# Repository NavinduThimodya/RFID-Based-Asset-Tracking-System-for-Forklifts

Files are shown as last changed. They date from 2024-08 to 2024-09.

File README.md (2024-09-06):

### RFID-Based Asset Tracking Device for Forklifts

#### Overview:

This project aims to develop an RFID-based asset tracking device for forklifts, enhancing asset management efficiency in warehouse environments. The device utilizes RFID technology for asset identification and tracking, integrating with existing forklift systems to provide real-time visibility of asset movements. The system consists of an RFID reader mounted on the forklift, antennas for RFID signal transmission and reception, and a cloud-based platform for data storage and analysis.

#### Features:

*   **RFID Technology:** Utilizes HF RFID technology (13.56MHz) for asset tracking, ensuring reliable and accurate identification.
*   **Real-Time Tracking:** Provides real-time visibility of asset movements, enabling efficient inventory management and asset utilization.
*   **Cloud Connectivity:** Integrates with cloud-based platforms for data storage, analysis, and remote access.
*   **User Interface:** Includes LEDs and a buzzer for user feedback, indicating successful RFID reads and system status.
*   **Low Power Consumption:** Designed for low power consumption, ensuring long-term operation without frequent recharging or replacement of batteries.

#### Components:

*   **PN532 RFID Reader:** Interfaces with RFID tags to read and write data, enabling asset tracking functionality.
*   **ESP32 WROOM 32:** Provides WiFi connectivity for data transmission to cloud servers, enabling real-time tracking updates.
*   **LM2596S-3.3 Voltage Regulator:** Converts the 12V forklift battery voltage to 3.3V for powering the ESP32 and PN532.
*   **Antenna and Matching Circuit:** Enables efficient transmission and reception of RFID signals, ensuring reliable asset tracking.

#### Installation:

1.  **Mounting:** Attach the RFID reader and antennas to the forklift as per the installation instructions.
2.  **Power Supply:** Connect the device to the forklift battery using the provided power cable.
3.  **Network Connection:** Configure the device to connect to the WiFi network in the warehouse.
4.  **Software Setup:** Install the necessary software on the forklift's onboard computer to receive and process RFID data.

#### Usage:

1.  **Asset Tagging:** Attach RFID tags to assets to be tracked, ensuring they are within the reader's range.
2.  **Asset Tracking:** Drive the forklift as usual, and the RFID reader will automatically scan nearby assets and update their locations in real-time.
3.  **Data Analysis:** Use the cloud-based platform to analyze asset movements, optimize inventory placement, and improve overall warehouse efficiency.

#### Maintenance:

*   **Regular Inspections:** Periodically check the device for any physical damage or loose connections.
*   **Software Updates:** Keep the device's software up to date to ensure optimal performance and compatibility with the cloud platform.
*   **Battery Replacement:** Replace the forklift battery as needed to maintain continuous power supply to the device.

#### For More Details:

For a more detailed description of the project, including design specifications, circuit diagrams, and enclosure designs, please refer to the project's design document.

#### Achieving recognition as one of the top 3 projects in the module highlights my ability to deliver high-quality solutions that meet both technical and practical challenges. This accomplishment reflects my commitment to innovation, precision, and impactful engineering design.

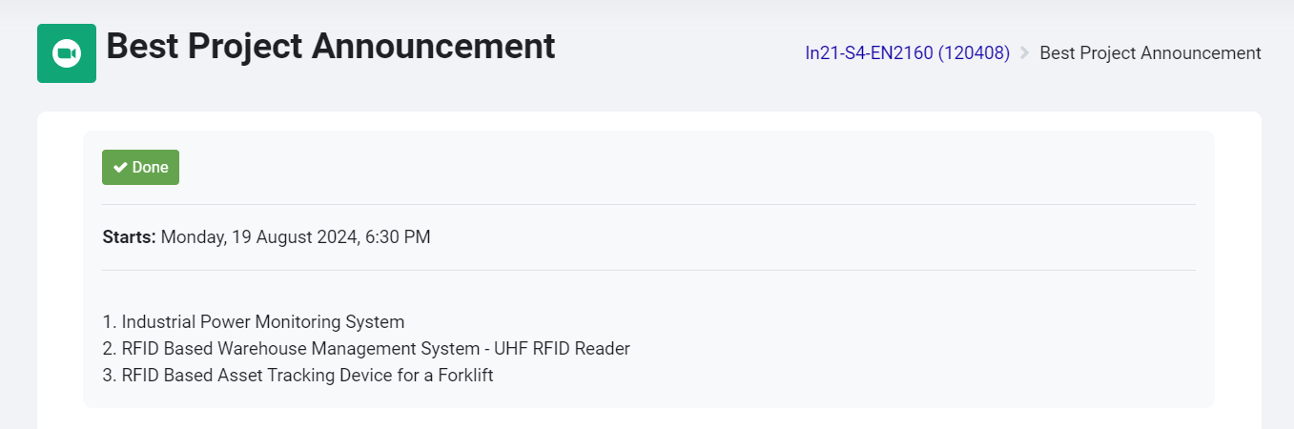
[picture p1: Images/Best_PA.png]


* * *

#### Enclosure Design:
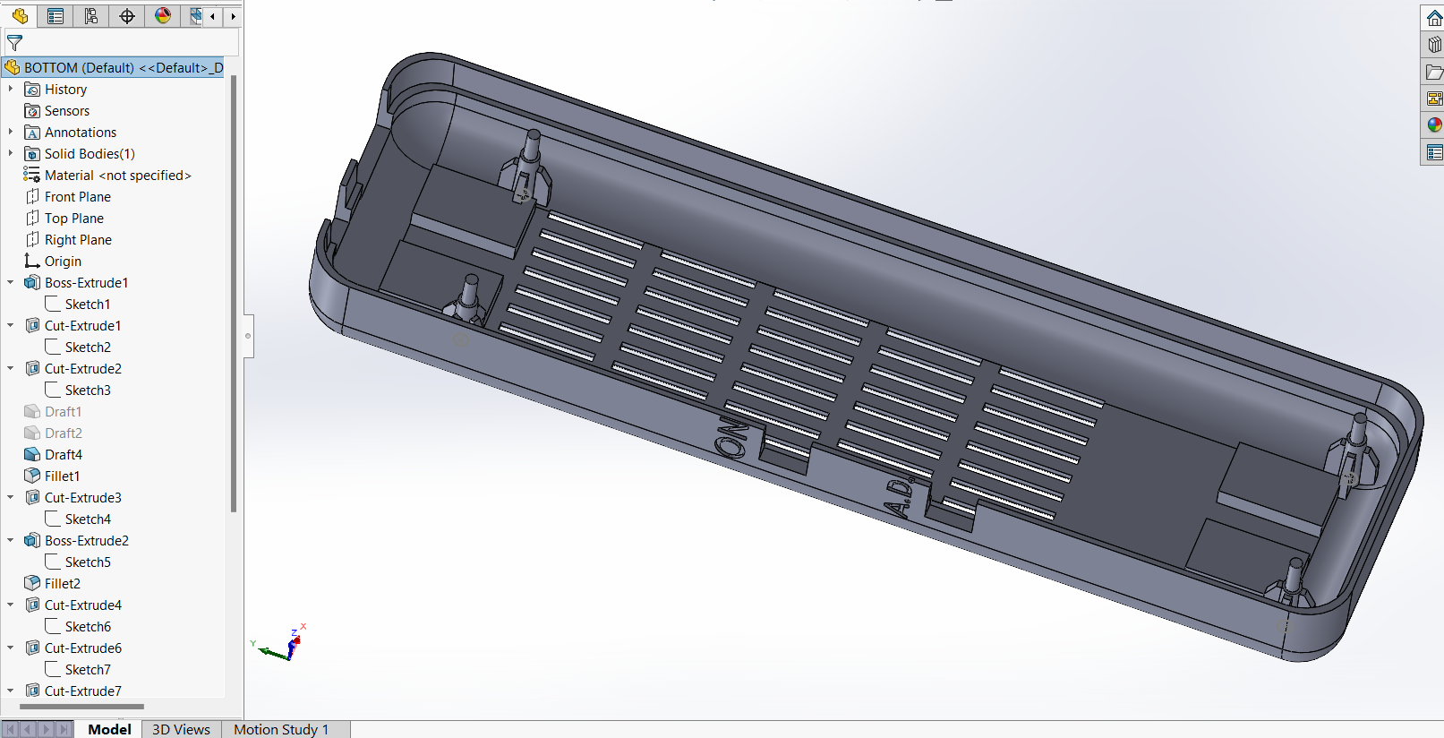
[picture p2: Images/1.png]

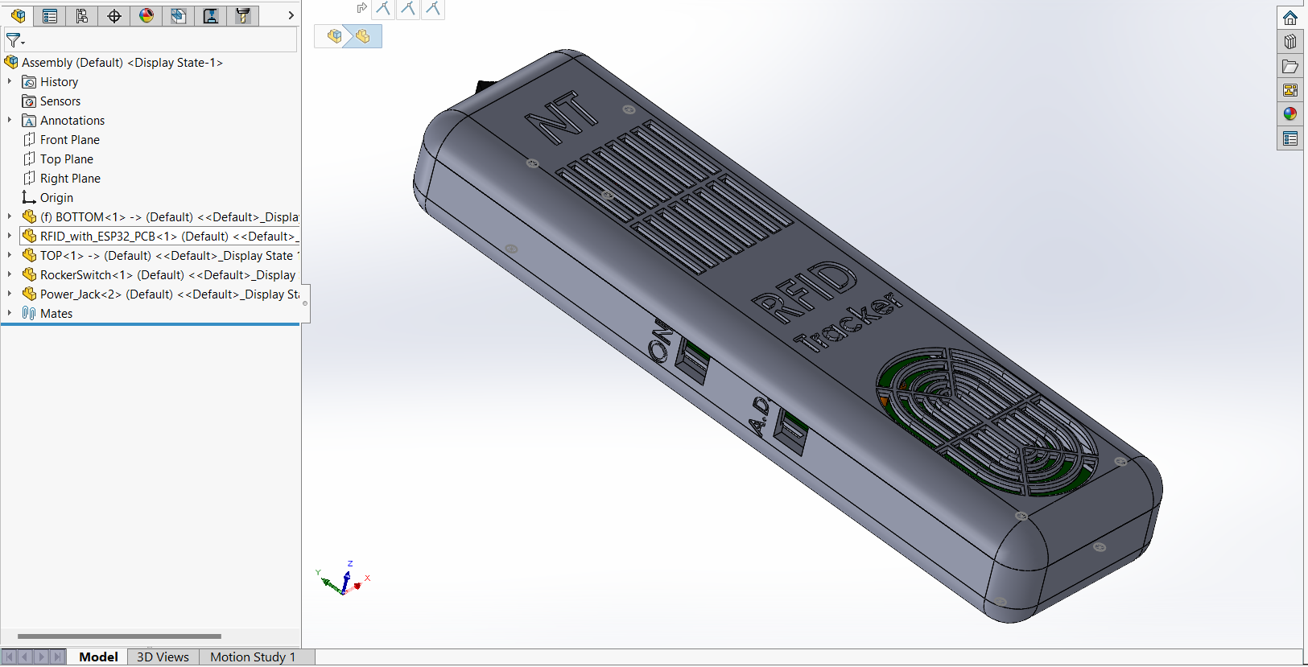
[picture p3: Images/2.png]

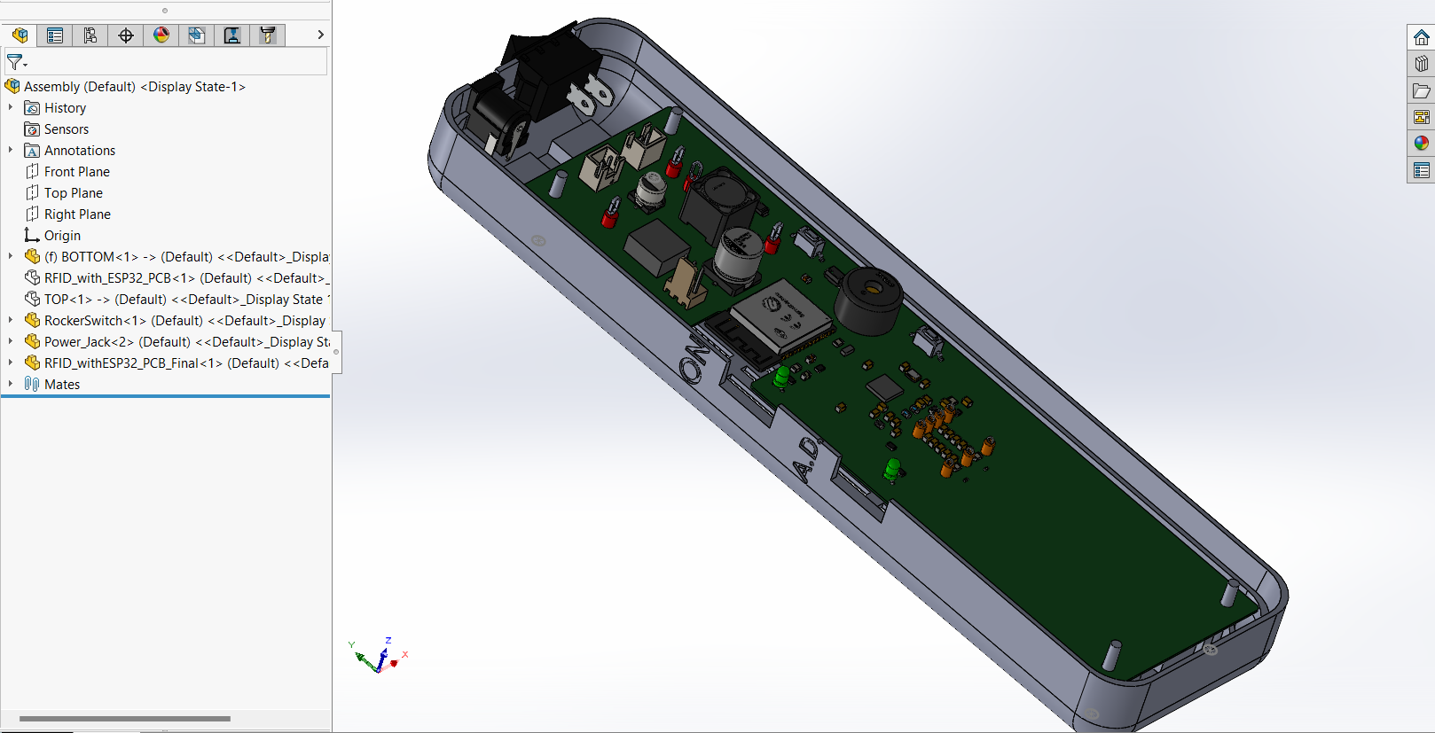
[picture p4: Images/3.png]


#### PCB Design:
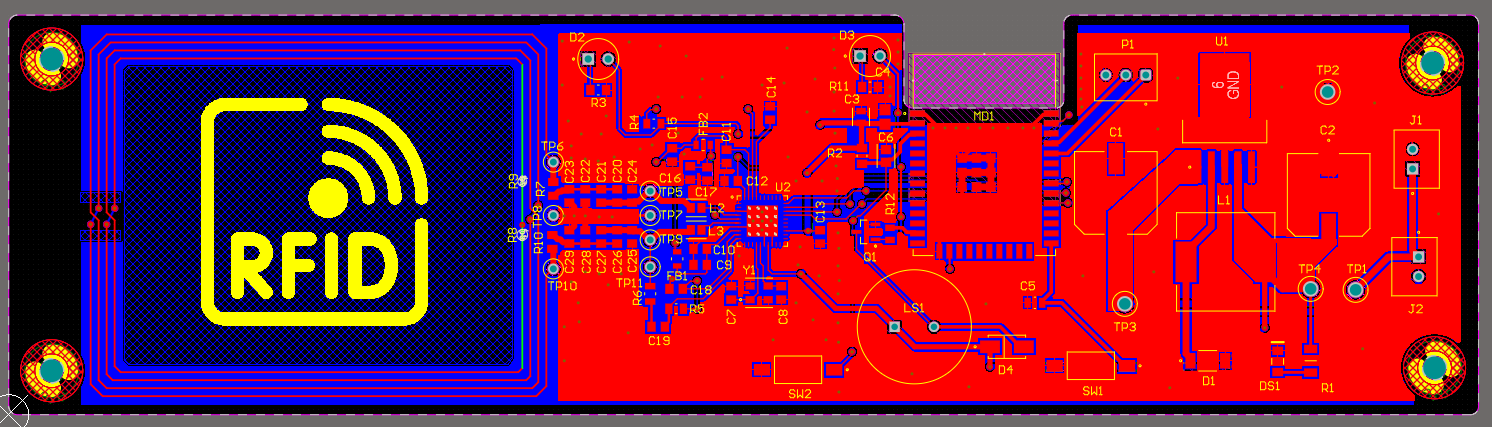
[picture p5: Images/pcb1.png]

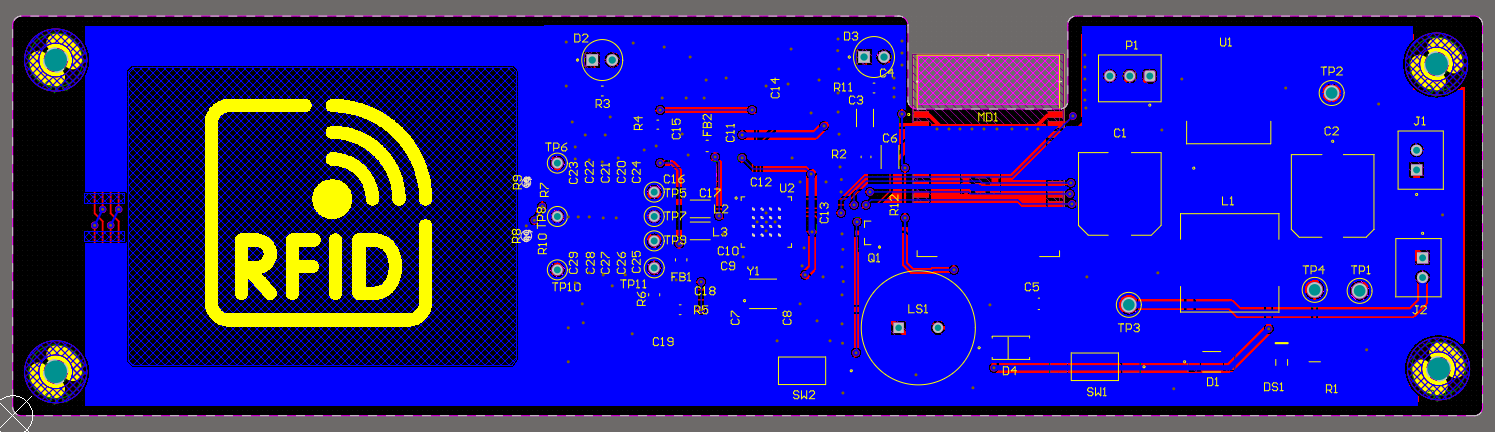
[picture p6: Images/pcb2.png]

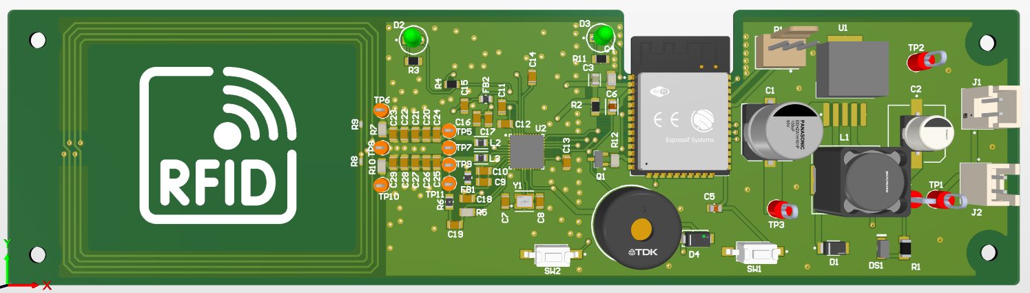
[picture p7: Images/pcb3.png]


#### Printed PCB:
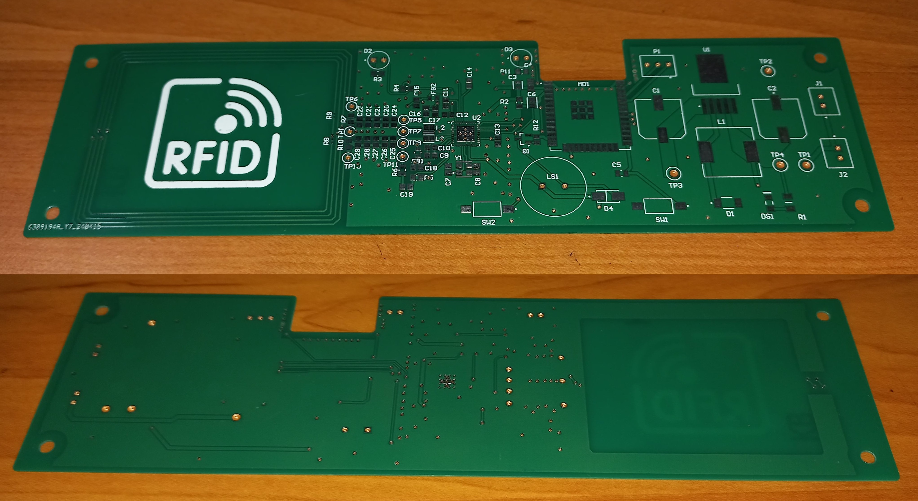
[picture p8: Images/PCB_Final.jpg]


#### Enclosure:
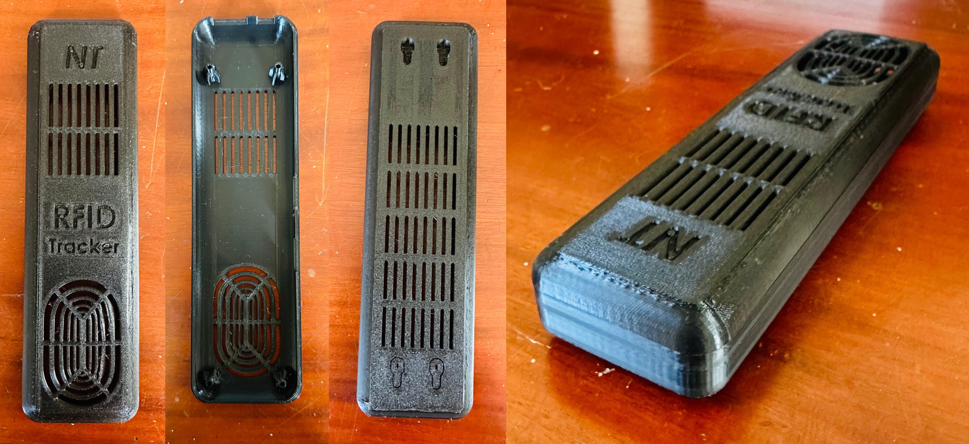
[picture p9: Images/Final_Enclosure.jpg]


#### Prototype:
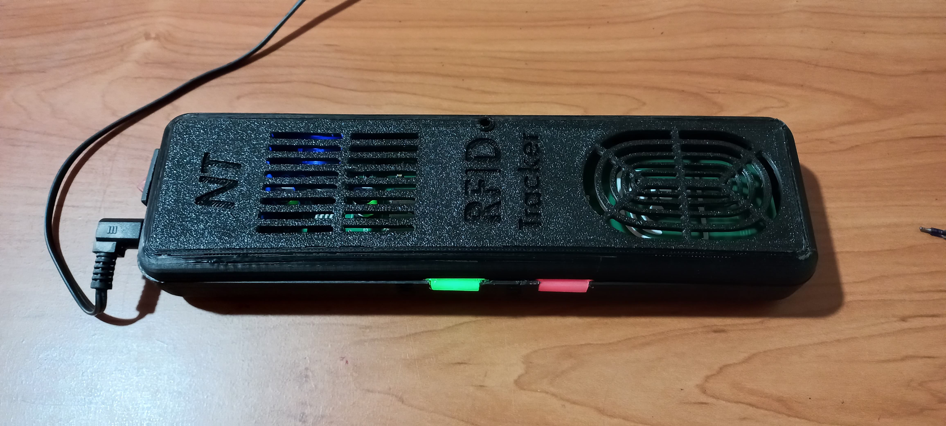
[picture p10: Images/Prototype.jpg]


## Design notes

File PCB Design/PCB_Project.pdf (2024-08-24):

Line # | Name | Description | Designator | Revision ID | Revision State | Revision Status | Quantity | Manufacturer 1 | Manufacturer Part Number 1 | Manufacturer Lifecycle 1 | Supplier 1 | Supplier Part Number 1 | Supplier Unit Price 1 | Supplier Subtotal 1
| 470uF | CAP ALUM POLY HYB 100UF 50V SMD | C1 | | Unknown server | | 1 | Panasonic | EEH-ZA1H101P | Volume Production
| 330uF | CAP ALUM 330UF 20% 35V SMD | C2 | | Unknown server | | 1 | Panasonic | EEE-FK1V331AP | Volume Production
| 10uF | CAP CER 10UF 10V X5R 0805 | C3 | | Unknown server | | 1
| 0.1uF | | C4 | | Unknown server | | 1
| 100nF | CAP CER 0.1UF 50V X7R 0805 | C5 | | Unknown server | | 1
| 100nF | General Purpose Ceramic Capacitor, 0805, 100nF, 10%, X7R, 15%, 100V | C6 | | Unknown server | | 1
| 33pF, 0.1uF, 10uF, 1000pF, NC, 22pF, 100pF, 220pF | Chip Capacitor, 0.1 uF, +/- 10%, 50 V, -55 to 125 degC, 0805 (2012 Metric), RoHS, Tape and Reel | C7, C8, C9, C10, C11, C12, C13, C14, C15, C16, C17, C18, C19, C20, C21, C22, C23, C24, C25, C26, C27, C28, C29 | | Unknown server | | 23
| CMS06(TE12L,Q,M) | DIODE SCHOTTKY 30V 2A MFLAT | D1 | | Unknown server | | 1 | Toshiba | CMS06(TE12L,Q,M) | Volume Production
| Power-LED, Detect-LED | TLLG4400 Led, Pcb, Green, 0.63MCD, 3MM, T-1, 7MA, 1.9V, 565NM, 25DEG, 20V, 20MW, -40 | D2, D3 | | Unknown server | | 2
| RS1M | DIODE GEN PURP 1KV 1A SMA | D4 | | Unknown server | | 1
| SML-LX1206IC-TR | LED Red, 65 mW, -40 to 85 degC, 2-Pin SMD, RoHS, Tape and Reel | DS1 | | Unknown server | | 1 | Lumex | SMLLX1206ICTR | Volume Production
| HZ0805B272R-10 | FERRITE BEAD 100 OHM 0805 1LN | FB1, FB2 | | Unknown server | | 2
| B2B-XH-A(LF)(SN), Switch | CONN HEADER VERT 2POS 2.5MM, To power Switch | J1, J2 | | Unknown server | | 2 JST | | B2B-XH-A(LF)(SN) | Volume Production
| SRR1210-101M | FIXED IND 100UH 2.5A 135MOHM SMD | L1 | | Unknown server | | 1 | Bourns | SRR1210-101M | Volume Production
| 560nH | Multilayer Type Inductor for General Circuits, 0805 (2012), 0.56μH, 10%, 0.63Ω, 150mA | L2, L3 | | Unknown server | | 2
| BUZZER | AUDIO PIEZO TRANSDUCER 30V TH | LS1 | | Unknown server | | 1
| ESP32-WROOM-32 | RX TXRX MOD WIFI SURFACE MOUNT | MD1 | | Unknown server | | 1 | Espressif Systems | ESP32-WROOM-32
| 61900311121 | | P1 | | Unknown server | | 1
| BC847C | NPN Silicon AF Transistor, 45 V VCEO, 100 mA IC, SOT23, Reel, Green | Q1 | | Unknown server | | 1
| 1K | Resistor | R1 | | Not managed | | 1
| 1K | Chip Resistor, 1 KOhm, +/- 1%, 125 mW, -55 to 155 degC, 0805 (2012 Metric), RoHS, Tape and Reel | R2 | | Unknown server | | 1
| 10R | Chip Resistor, 10 Ohm, +/- 1%, 0.125 W, -55 to 155 degC, 0805 (2012 Metric), RoHS, Tape and Reel | R3, R11 | | Unknown server | | 2
| 10K | Chip Resistor, 10 KOhm, +/- 1%, 0.125 W, -55 to 155 degC, 0805 (2012 Metric), RoHS, Tape and Reel | R4 | | Unknown server | | 1
| 1.0K | | R5 | | Unknown server | | 1
| 1.69K | RES Thick Film, 1.5kΩ, 1%, 0.125W, 100ppm/°C, 0805 | R6 | | Unknown server | | 1
| 1.5 | | R7, R10 | | Unknown server | | 2
| NC | | R8, R9 | | Unknown server | | 2
| 220R | | R12 | | Unknown server | | 1
| Boot Button, RESET Button | FSMSM Push Button Switch, 50 mA, -35 to 85 degC, 2-Pin SMD, RoHS, Bulk | SW1, SW2 | | Unknown server | | 2
| 12V_IN, GND, 12V, 3.3V | Test Point, Red, Through Hole, RoHS, Bulk | TP1, TP2, TP3, TP4 | | Unknown server | | 4
| TX1_POST, TX1_PRE, TGND, TX2_POST, TX2_PRE, RX | Test Point, Orange, 1-Pin THD, RoHS | TP5, TP6, TP7, TP8, TP9, TP10, TP11 | | Unknown server | | 7
| LM2596S-3.3 | SIMPLE SWITCHER® Power Converter 150 KHz 3A Step-Down Voltage Regulator, 5-pin TO-263 | U1 | | Unknown server | | 1 | TI National Semiconductor | LM2596S-3.3 | End of Life
| PN5321A3HN/C106;55 | NFC Controller, 13.56 MHz, -30 to 85 degC, 40-Pin HVQFN (SOT618-1), RoHS, Tray | U2 | | Unknown server | | 1
| ABM8-27.120MHZ-B4-T | Crystal 27.12MHz ±30ppm 18pF SMD-4 3.2mm x 2.5mm | Y1 | | Unknown server | | 1

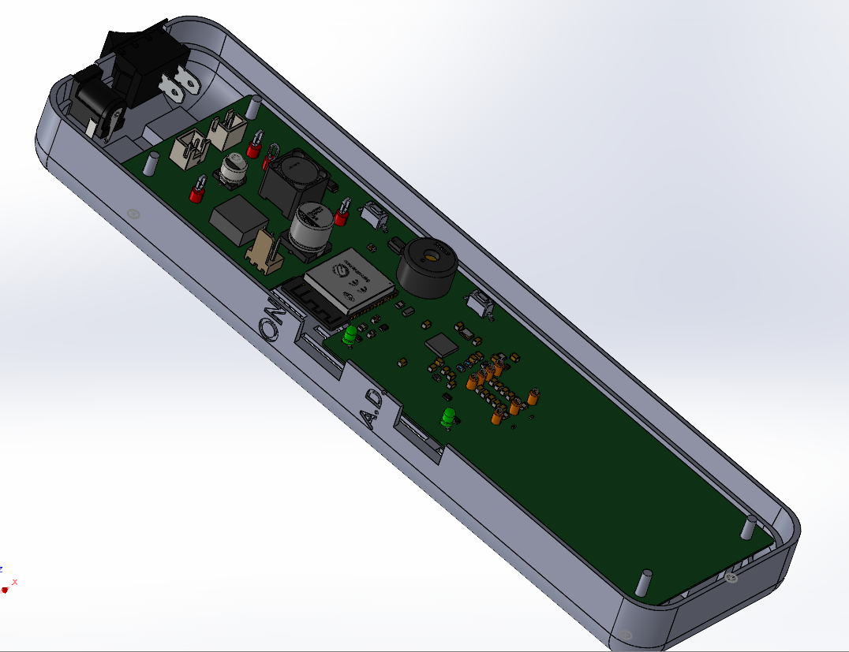
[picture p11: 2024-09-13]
Images/3 - Copy.png

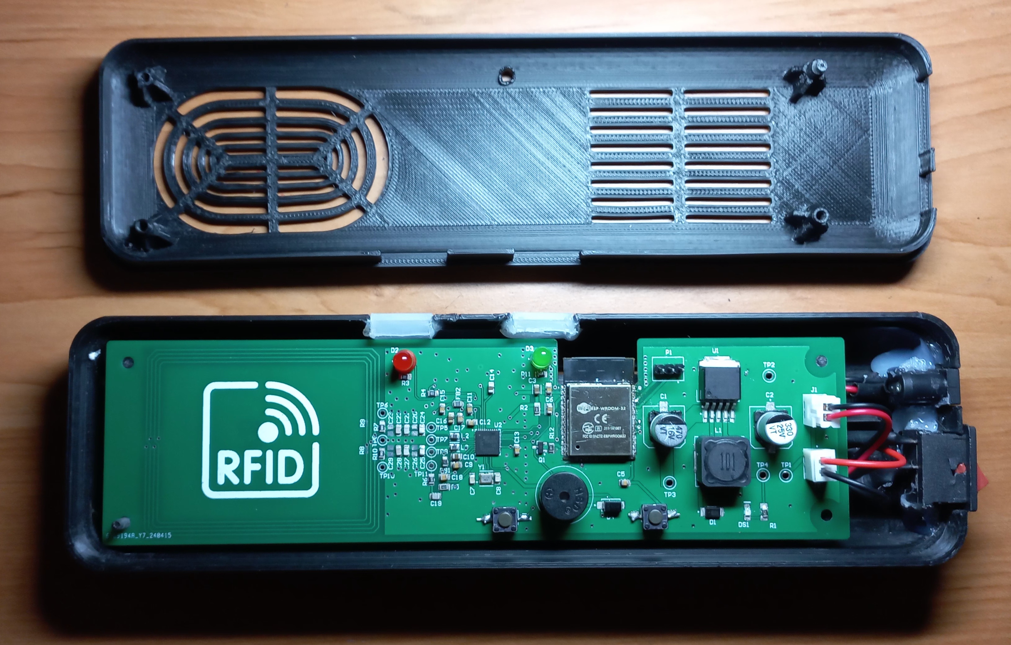
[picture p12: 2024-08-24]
Images/Integration.jpg

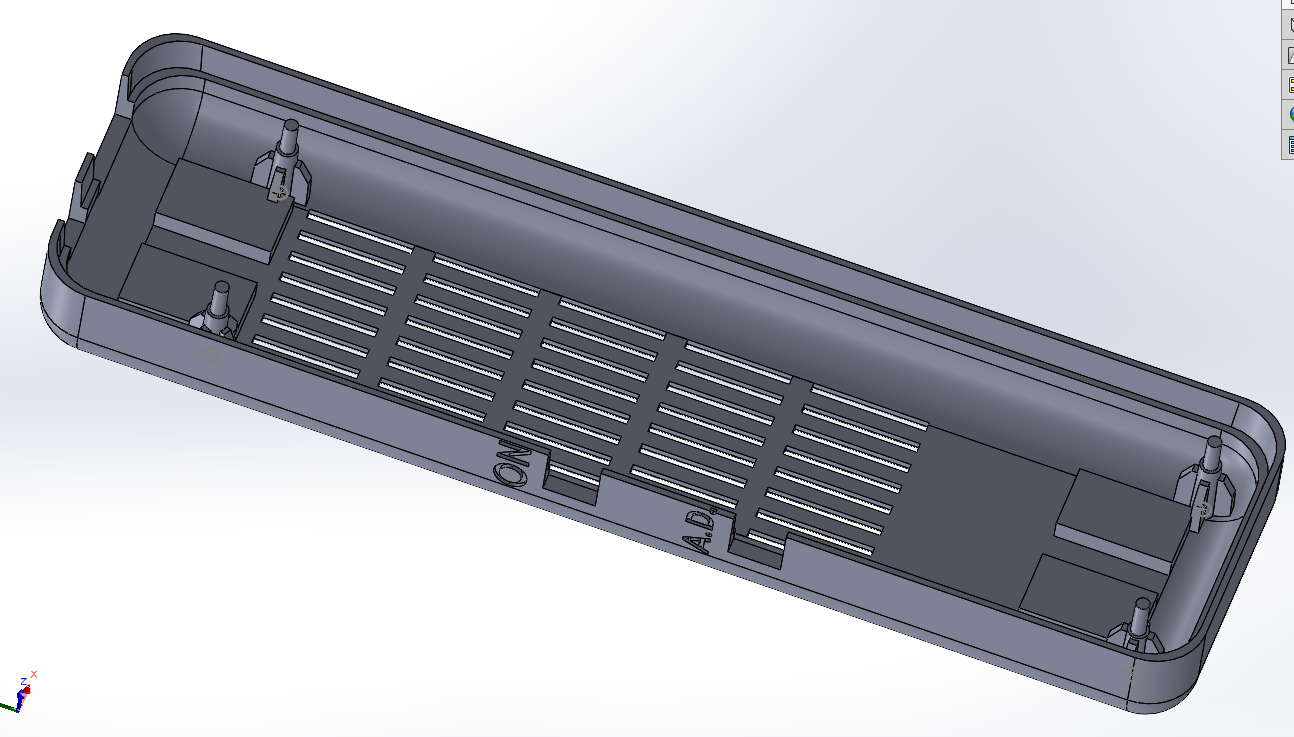
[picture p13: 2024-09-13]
Images/1 - Copy.png

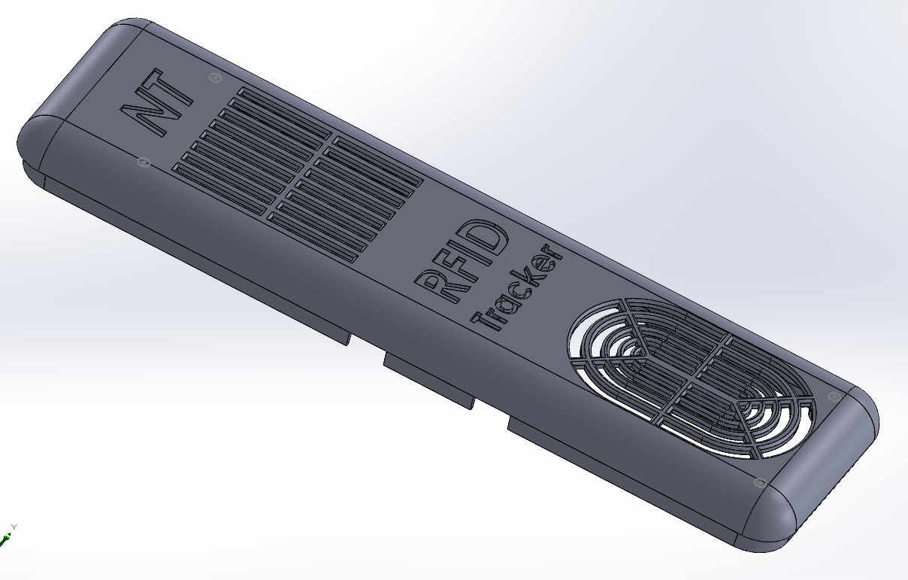
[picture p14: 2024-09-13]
Images/4 - Copy.png

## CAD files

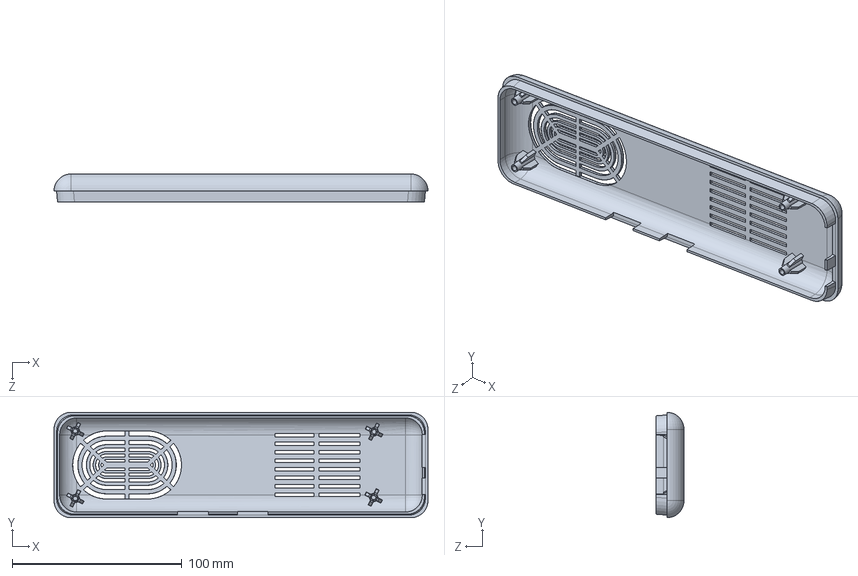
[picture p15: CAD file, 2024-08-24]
Enclosure Design/TOP.SLDPRT
220.0 x 62.0 x 16.5 mm

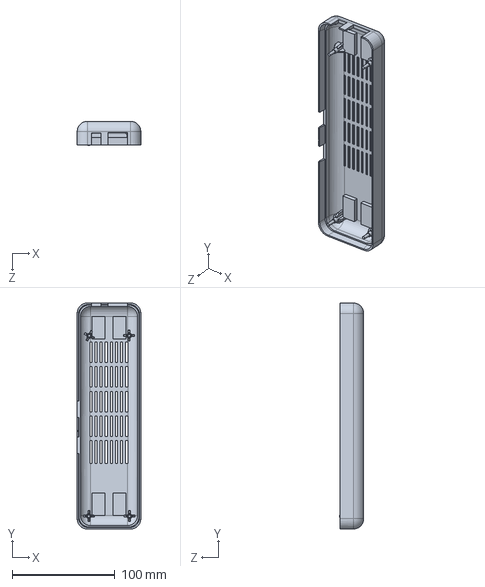
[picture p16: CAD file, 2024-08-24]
Enclosure Design/BOTTOM.SLDPRT
62.0 x 220.0 x 23.7 mm

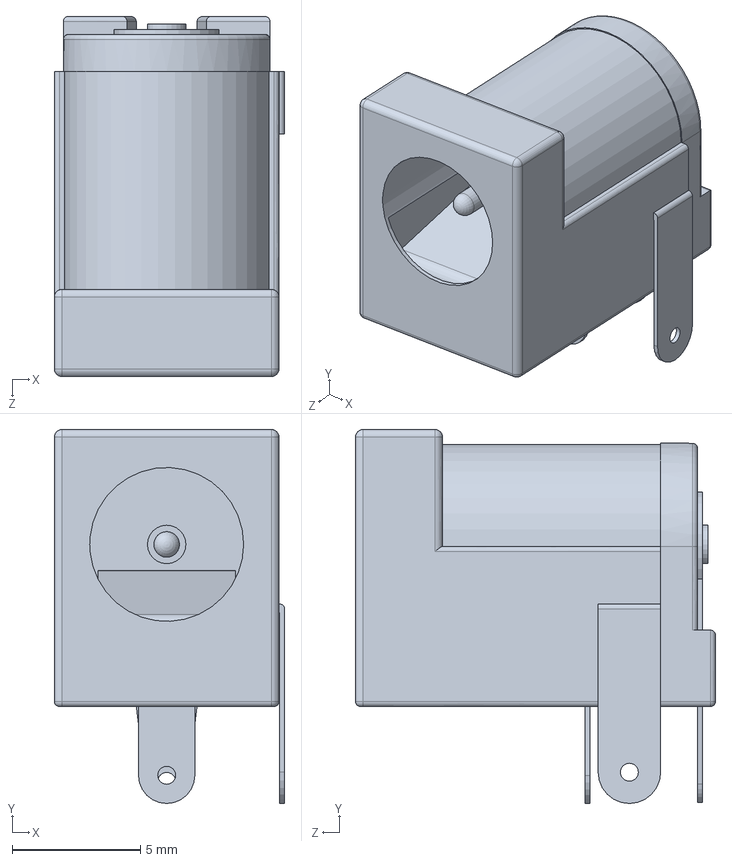
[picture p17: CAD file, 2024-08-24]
Enclosure Design/Power_Jack.SLDPRT
8.98 x 14.6 x 14.0 mm

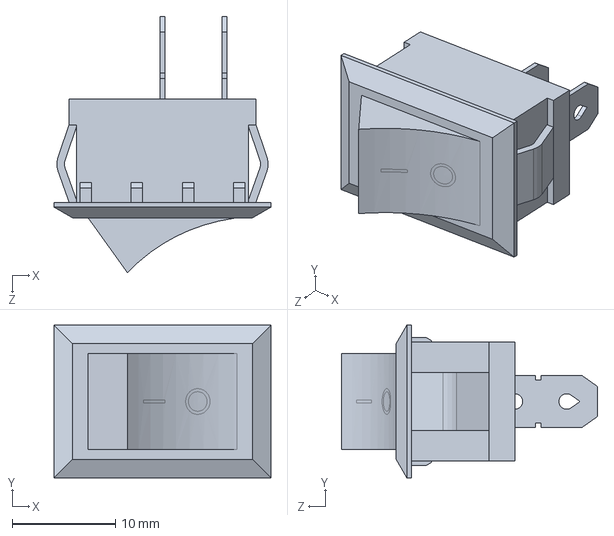
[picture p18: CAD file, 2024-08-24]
Enclosure Design/RockerSwitch.SLDPRT
21.0 x 14.8 x 24.8 mm

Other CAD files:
Enclosure Design/BOTTOM.STL
Enclosure Design/TOP.STL

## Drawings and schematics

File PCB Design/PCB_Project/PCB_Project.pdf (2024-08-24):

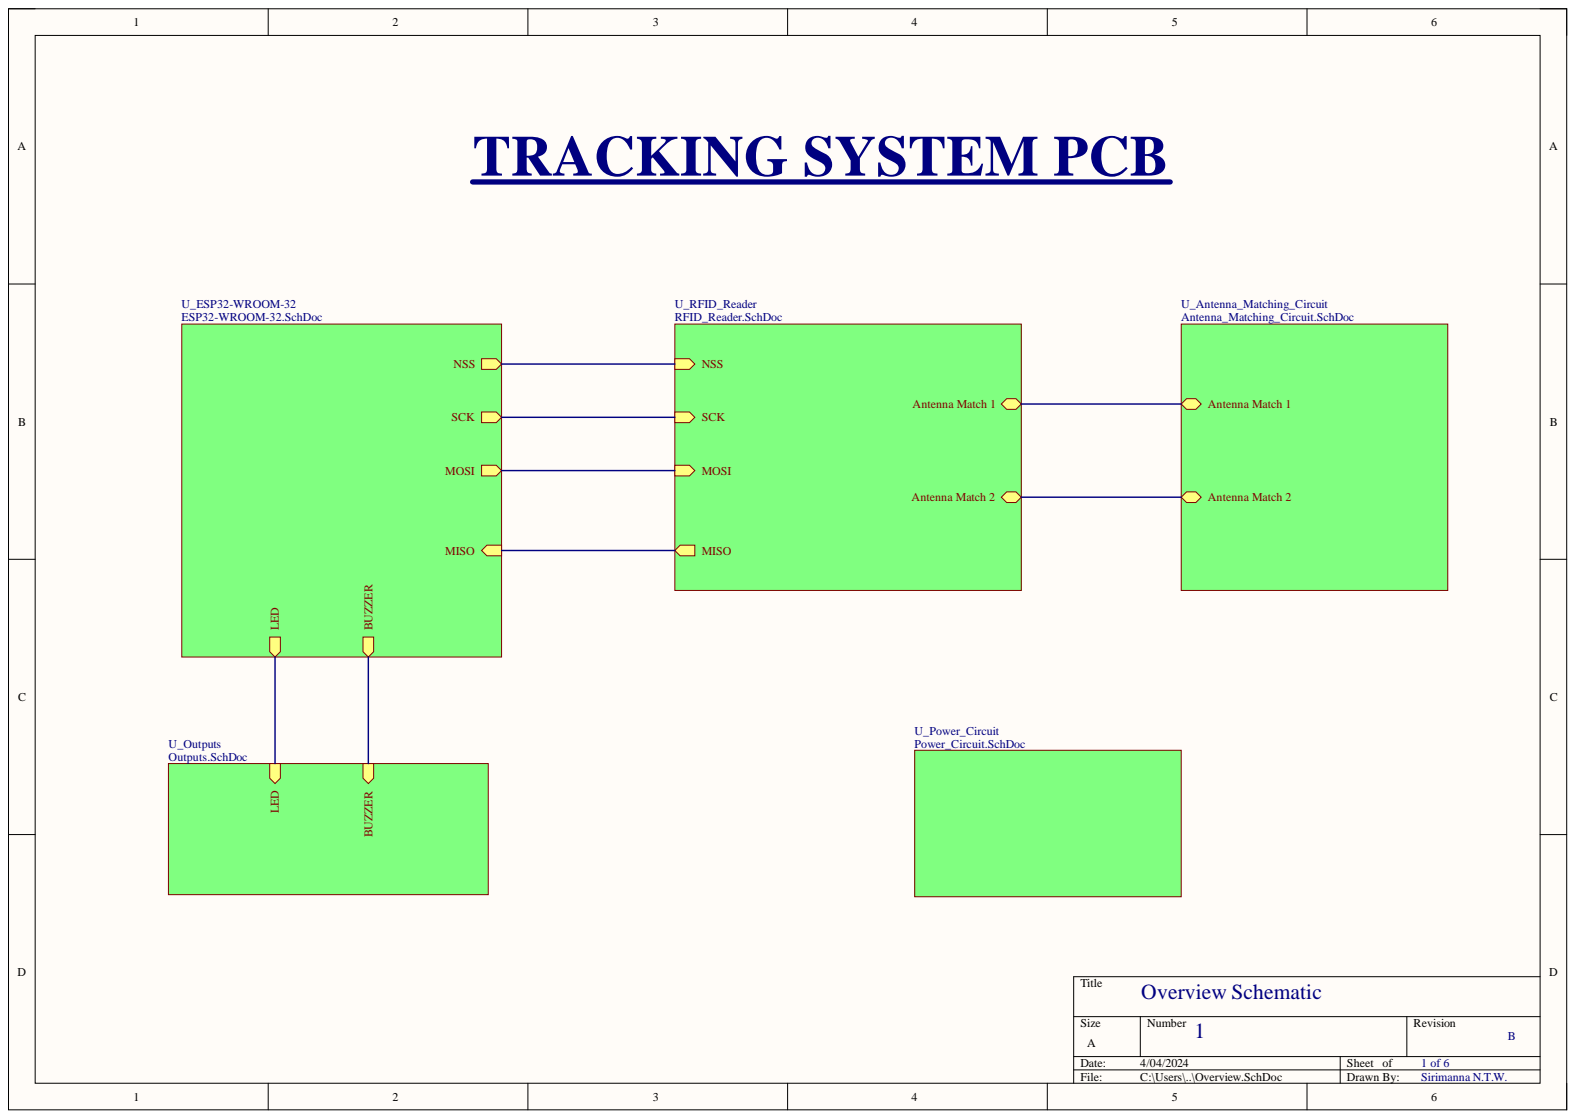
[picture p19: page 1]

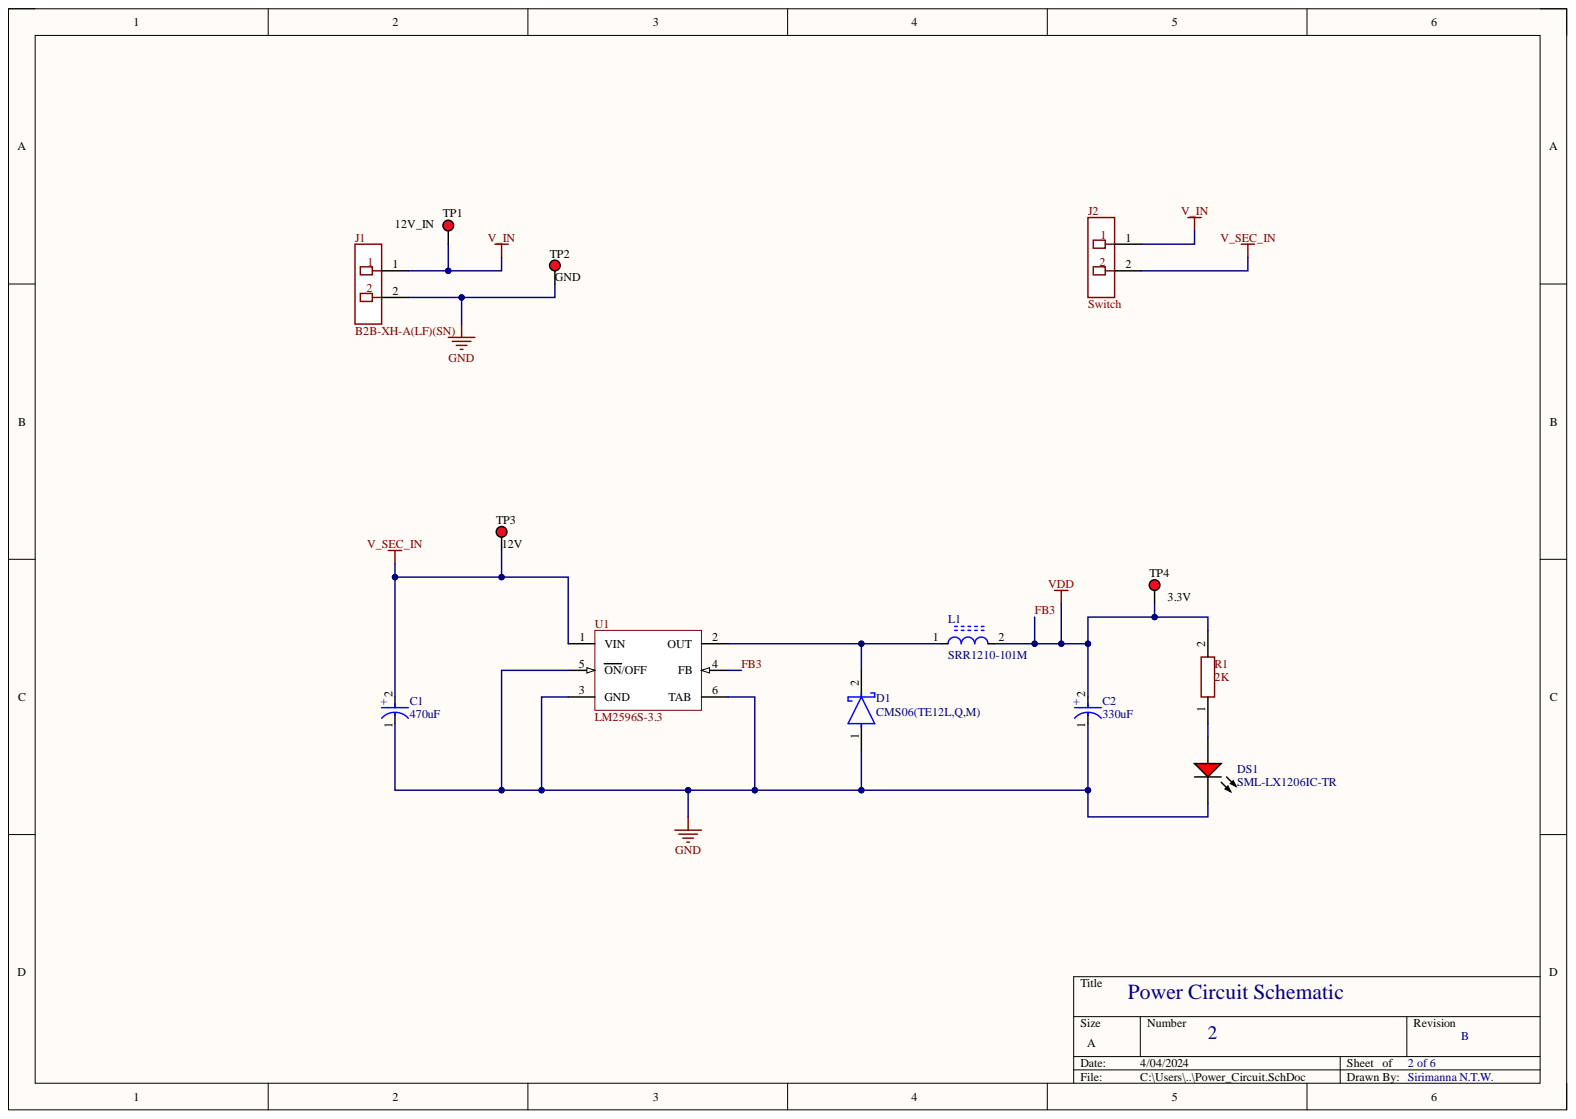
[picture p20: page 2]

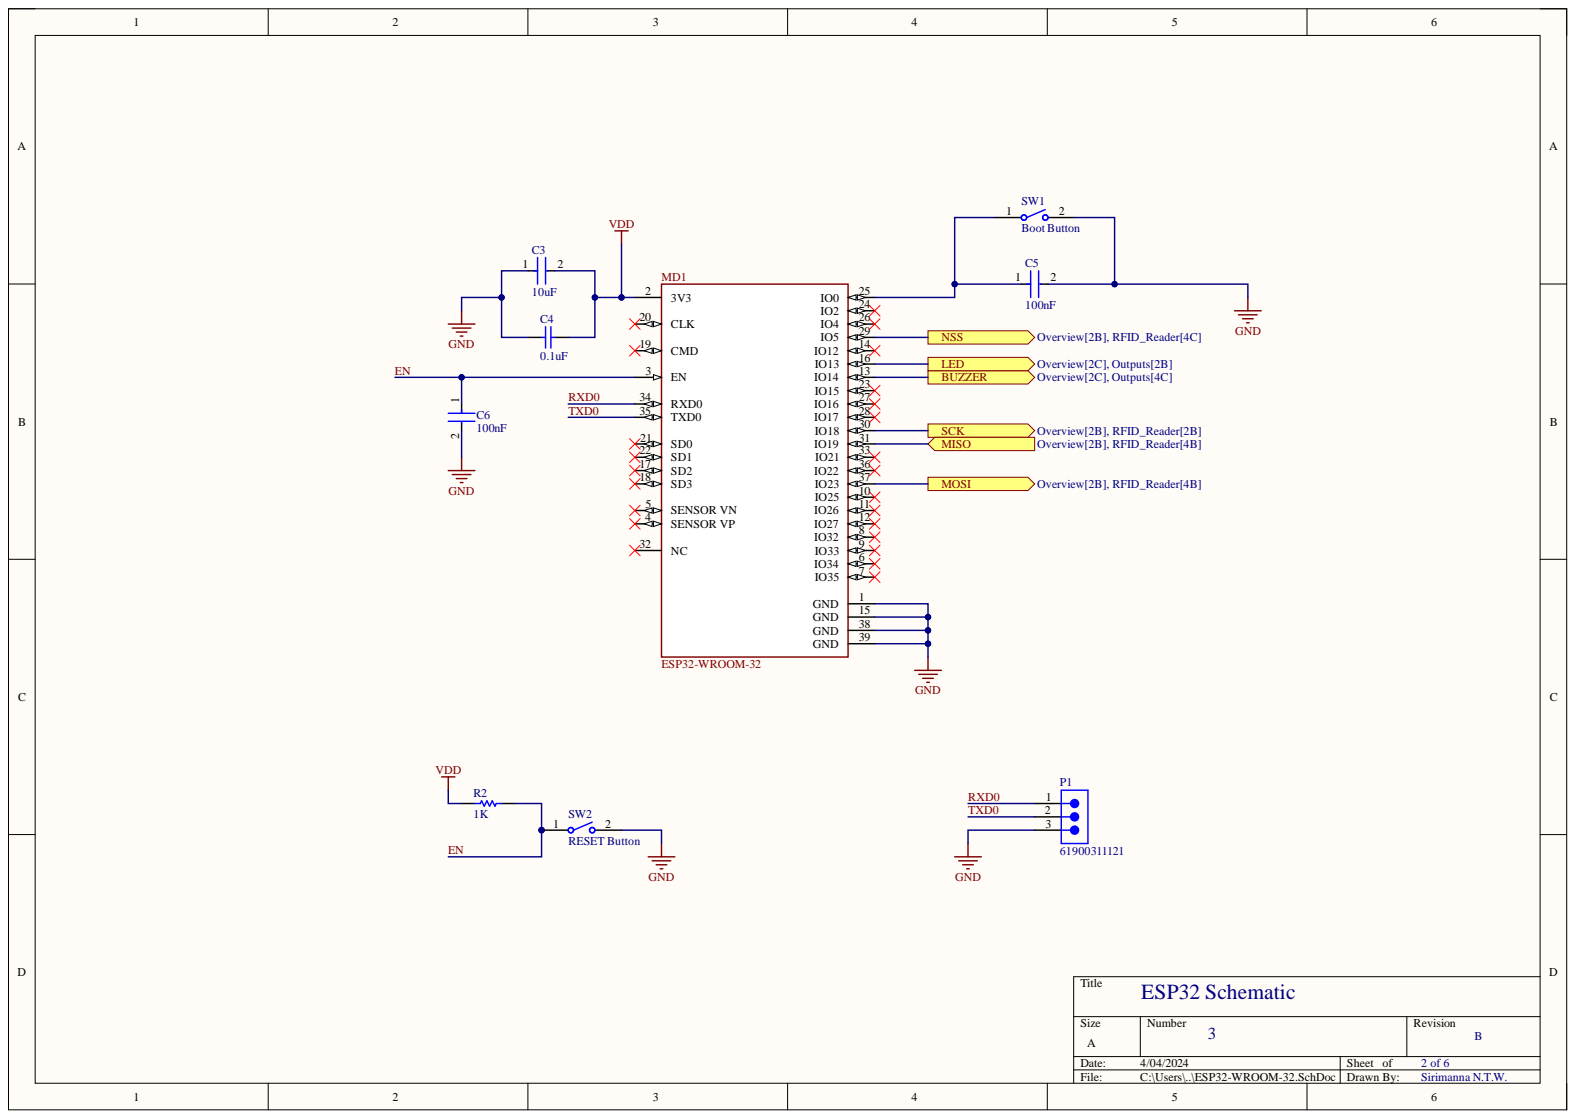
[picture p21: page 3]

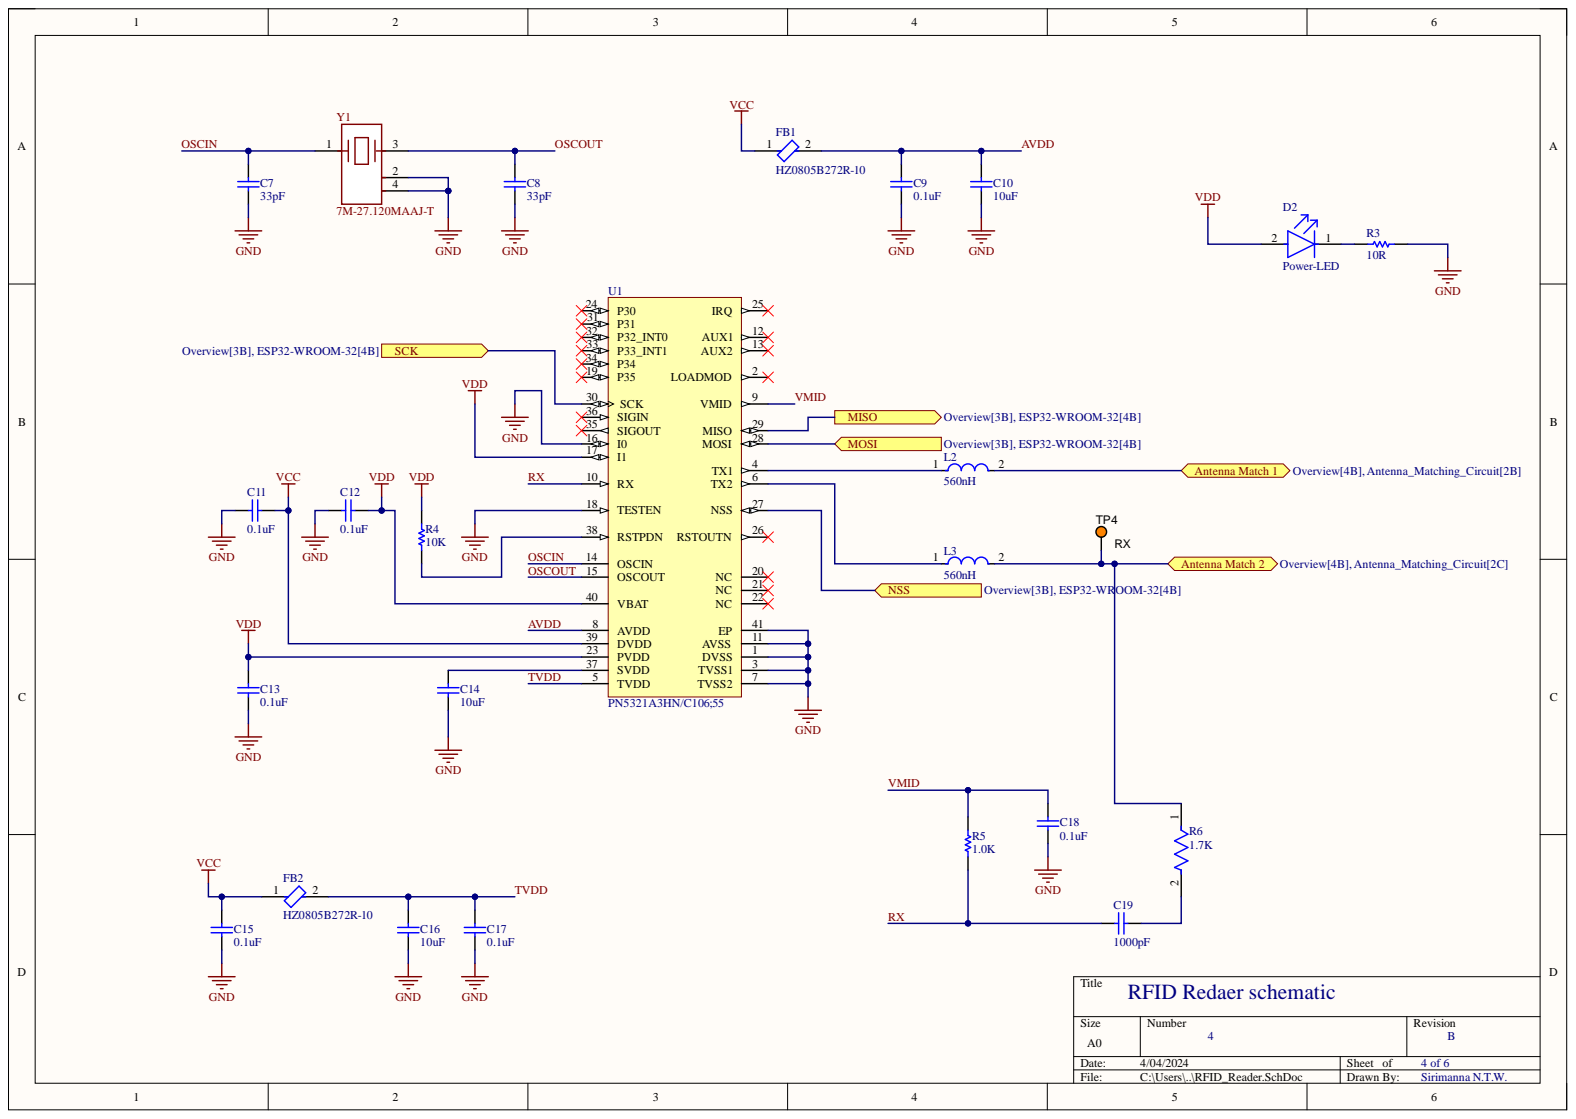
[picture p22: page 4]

R4 | RSTPDN 38
10K OSCIN | OSCIN 14

SVDD 37

TVDD | TVDD 5

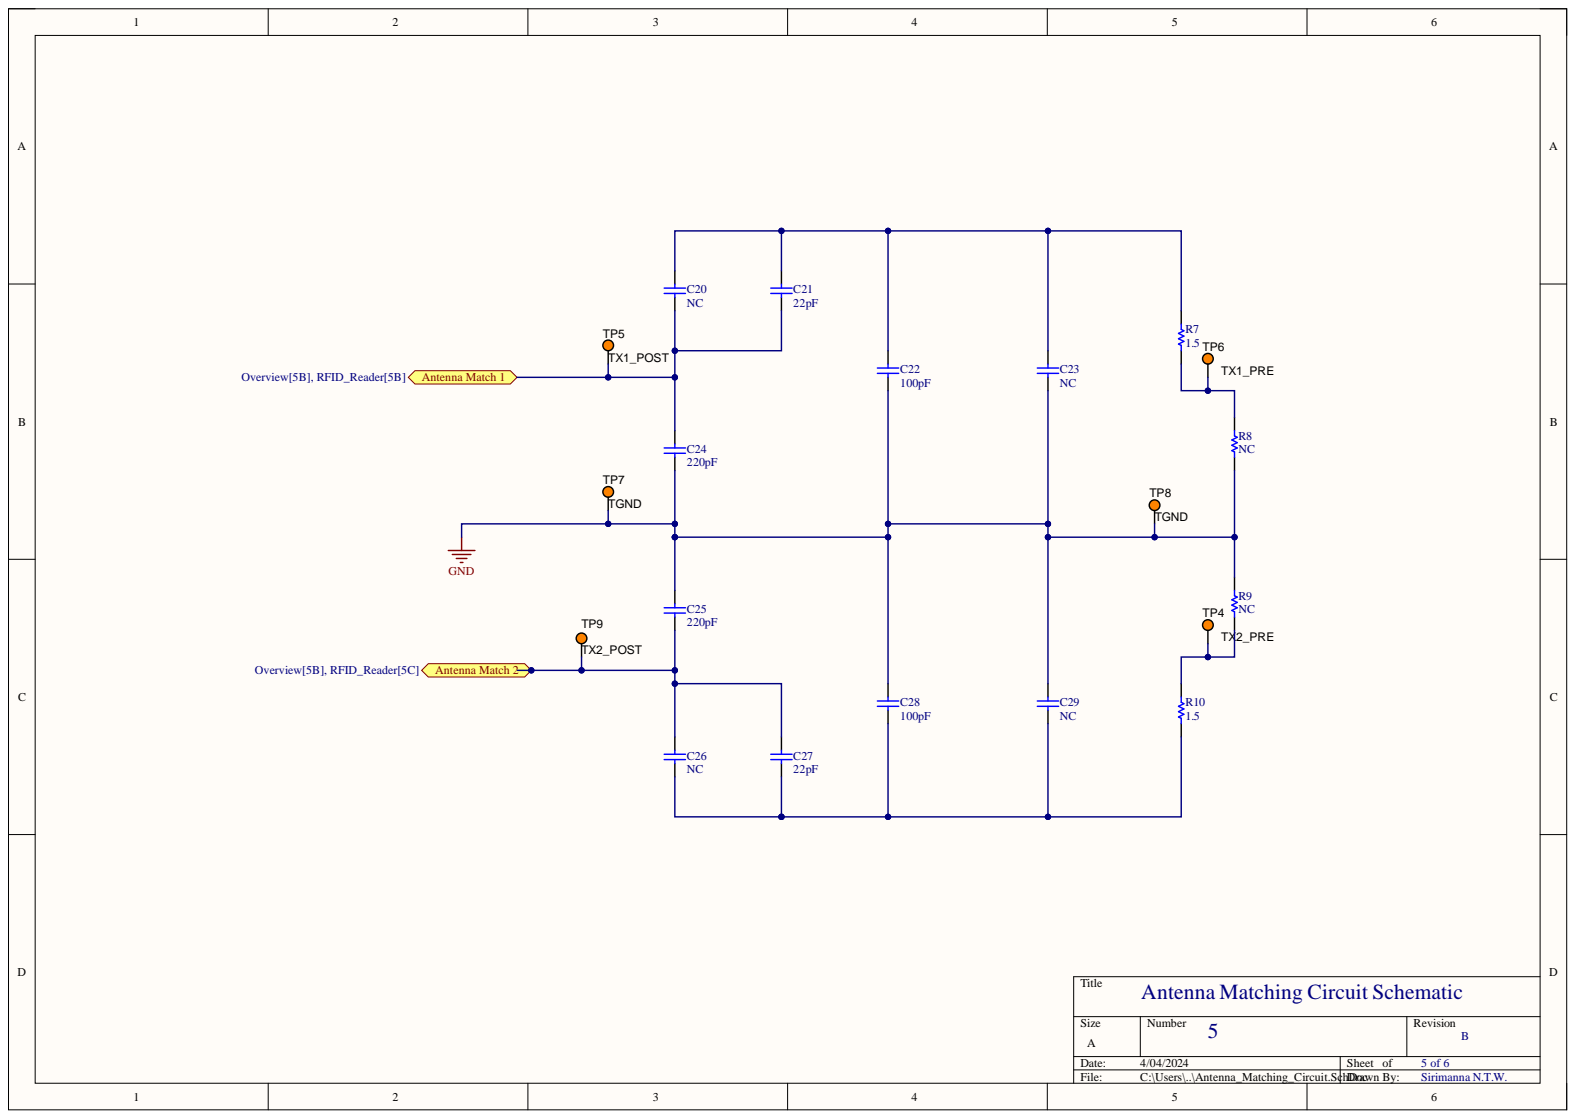
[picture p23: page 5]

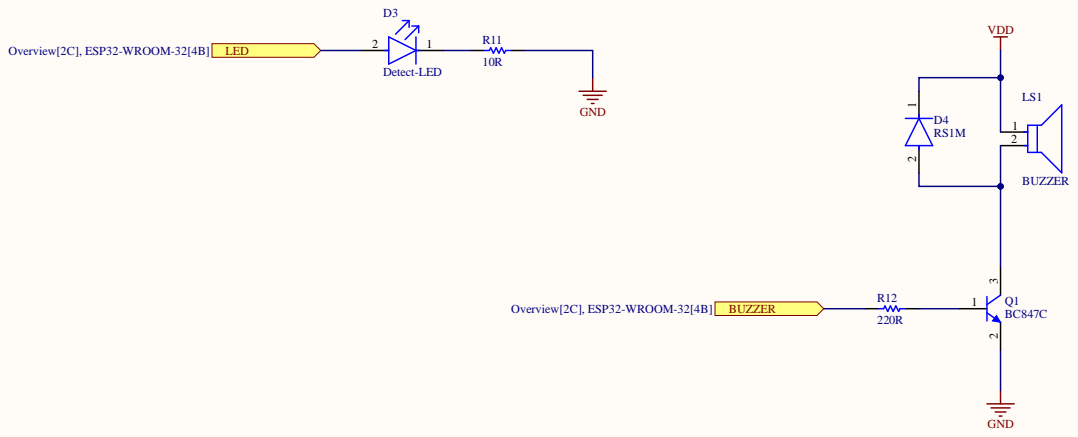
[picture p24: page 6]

Buzzer and LED Schematic

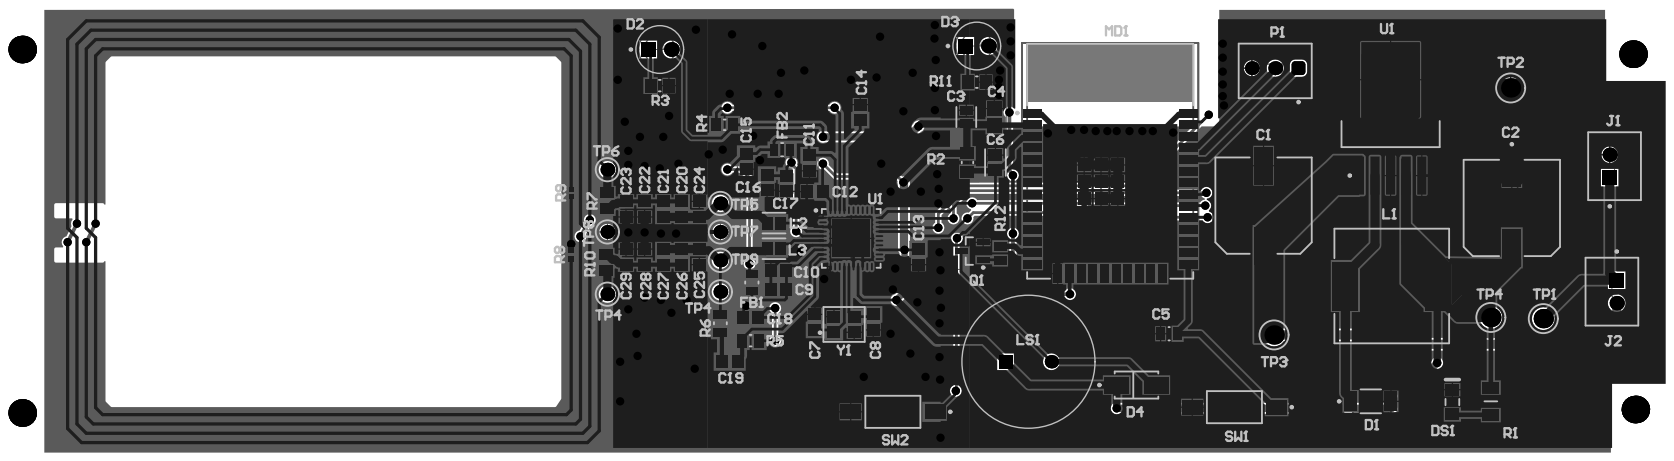
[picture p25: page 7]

Line # | Name | Description | Designator | Revision ID | Revision State | Revision Status | Quantity | Manufacturer 1 | Manufacturer Part Number 1 | Manufacturer Lifecycle 1 | Supplier 1 | Supplier Part Number 1 | Supplier Unit Price 1 | Supplier Subtotal 1
| 470uF | CAP ALUM POLY HYB 100UF 50V SMD | C1 | | Unknown server | | 1 | Panasonic | EEH-ZA1H101P | Volume Production | Newark | 62W7360 | 2.45 | 2.45
| 330uF | CAP ALUM 330UF 20% 35V SMD | C2 | | Unknown server | | 1 | Panasonic | EEE-FK1V331AP | Volume Production | Newark | 85AK4248 | 0.951 | 0.951
| 10uF | CAP CER 10UF 10V X5R 0805 | C3 | | Unknown server | | 1
| 0.1uF | | C4 | | Unknown server | | 1
| 100nF | CAP CER 0.1UF 50V X7R 0805 | C5 | | Unknown server | | 1
| 100nF | General Purpose Ceramic Capacitor, 0805, 100nF, 10%, X7R, 15%, 100V | C6 | | Unknown server | | 1
| 33pF, 0.1uF, 10uF, 1000pF, NC, 22pF, 100pF, 220pF | Chip Capacitor, 0.1 uF, +/- 10%, 50 V, -55 to 125 degC, 0805 (2012 Metric), RoHS, Tape and Reel | C7, C8, C9, C10, C11, C12, C13, C14, C15, C16, C17, C18, C19, C20, C21, C22, C23, C24, C25, C26, C27, C28, C29 | | Unknown server | | 23
| CMS06(TE12L,Q,M) | DIODE SCHOTTKY 30V 2A MFLAT | D1 | | Unknown server | | 1 | Toshiba | CMS06(TE12L,Q,M) | Volume Production | Arrow Electronics | CMS06(TE12L,Q,M) | 0.4278 | 0.4278
| Power-LED, Detect-LED | TLLG4400 Led, Pcb, Green, 0.63MCD, 3MM, T-1, 7MA, 1.9V, 565NM, 25DEG, 20V, 20MW, -40 | D2, D3 | | Unknown server | | 2
| RS1M | DIODE GEN PURP 1KV 1A SMA | D4 | | Unknown server | | 1
| SML-LX1206IC-TR | LED Red, 65 mW, -40 to 85 degC, 2-Pin SMD, RoHS, Tape and Reel | DS1 | | Unknown server | | 1 | Lumex | SMLLX1206ICTR | Volume Production | Arrow Electronics | SML-LX1206IC-TR | 0.2518 | 0.2518
| HZ0805B272R-10 | FERRITE BEAD 100 OHM 0805 1LN | FB1, FB2 | | Unknown server | | 2
| B2B-XH-A(LF)(SN), Switch | CONN HEADER VERT 2POS 2.5MM, To power Switch | J1, J2 | | Unknown server | | 2 JST | | B2B-XH-A(LF)(SN) | Volume Production | Newark | 73M9415 | 0.077 | 0.154
| SRR1210-101M | FIXED IND 100UH 2.5A 135MOHM SMD | L1 | | Unknown server | | 1 | Bourns | SRR1210-101M | Volume Production | Mouser | 652-SRR1210-101M | 1.23 | 1.23
| 560nH | Multilayer Type Inductor for General Circuits, 0805 (2012), 0.56μH, 10%, 0.63Ω, 150mA | L2, L3 | | Unknown server | | 2
| BUZZER | AUDIO PIEZO TRANSDUCER 30V TH | LS1 | | Unknown server | | 1
| ESP32-WROOM-32 | RX TXRX MOD WIFI SURFACE MOUNT | MD1 | | Unknown server | | 1 | Espressif Systems | ESP32-WROOM-32
| 61900311121 | | P1 | | Unknown server | | 1
| BC847C | NPN Silicon AF Transistor, 45 V VCEO, 100 mA IC, SOT23, Reel, Green | Q1 | | Unknown server | | 1
| 2K | Resistor | R1 | | Not managed | | 1
| 1K | Chip Resistor, 1 KOhm, +/- 1%, 125 mW, -55 to 155 degC, 0805 (2012 Metric), RoHS, Tape and Reel | R2 | | Unknown server | | 1
| 10R | Chip Resistor, 10 Ohm, +/- 1%, 0.125 W, -55 to 155 degC, 0805 (2012 Metric), RoHS, Tape and Reel | R3, R11 | | Unknown server | | 2
| 10K | Chip Resistor, 10 KOhm, +/- 1%, 0.125 W, -55 to 155 degC, 0805 (2012 Metric), RoHS, Tape and Reel | R4 | | Unknown server | | 1
| 1.0K | | R5 | | Unknown server | | 1
| 1.7K | RES Thick Film, 1.5kΩ, 1%, 0.125W, 100ppm/°C, 0805 | R6 | | Unknown server | | 1
| 1.5 | | R7, R10 | | Unknown server | | 2
| NC | | R8, R9 | | Unknown server | | 2
| 220R | | R12 | | Unknown server | | 1
| Boot Button, RESET Button | FSMSM Push Button Switch, 50 mA, -35 to 85 degC, 2-Pin SMD, RoHS, Bulk | SW1, SW2 | | Unknown server | | 2
| 12V_IN, GND, 12V, 3.3V | Test Point, Red, Through Hole, RoHS, Bulk | TP1, TP2, TP3, TP4 | | Unknown server | | 4
| TX2_PRE, RX, TX1_POST, TX1_PRE, TGND, TX2_POST | Test Point, Orange, 1-Pin THD, RoHS | TP4, TP5, TP6, TP7, TP8, TP9 | | Unknown server | | 7
| LM2596S-3.3 | SIMPLE SWITCHER® Power Converter 150 KHz 3A Step-Down Voltage Regulator, 5-pin TO-263 | U1 | | Unknown server | | 1 | TI National Semiconductor | LM2596S-3.3 | End of Life | Digikey | LM2596S-3.3-ND | 9.16 | 9.16
| PN5321A3HN/C106;55 | NFC Controller, 13.56 MHz, -30 to 85 degC, 40-Pin HVQFN (SOT618-1), RoHS, Tray | U1 | | Unknown server | | 1
| 7M-27.120MAAJ-T | Crystal 27.12MHz, 30ppm, 18pF, 50Ω | Y1 | | Unknown server | | 1

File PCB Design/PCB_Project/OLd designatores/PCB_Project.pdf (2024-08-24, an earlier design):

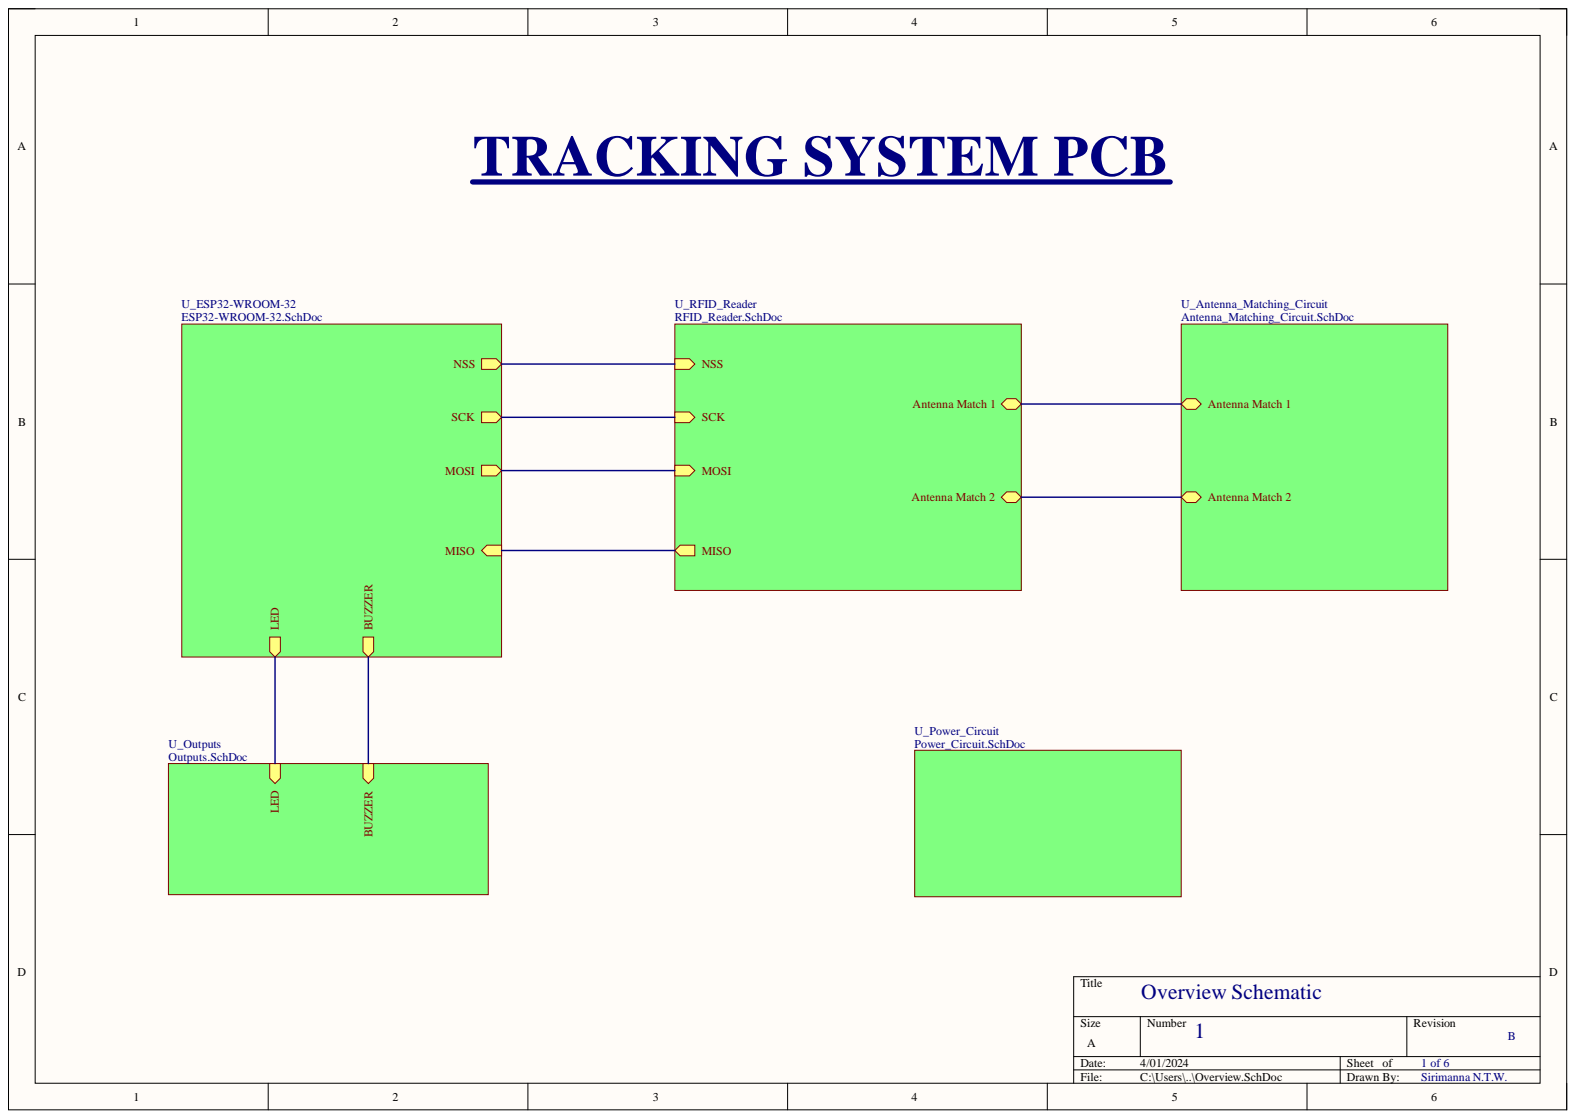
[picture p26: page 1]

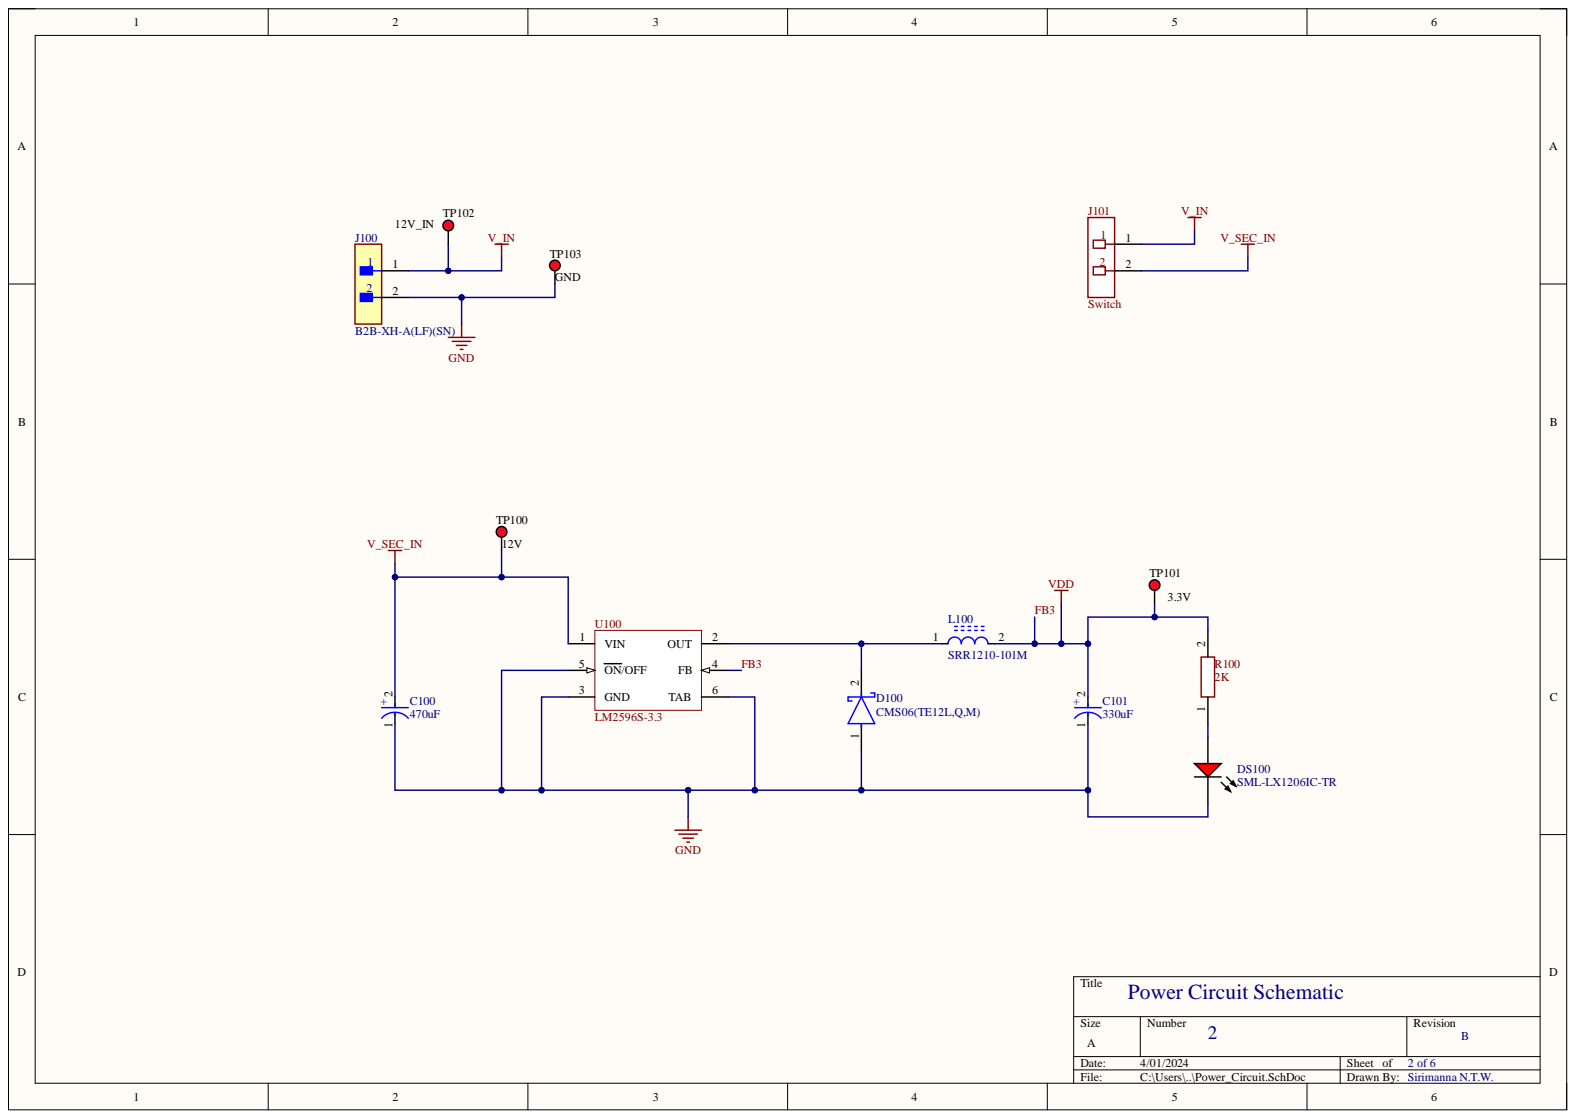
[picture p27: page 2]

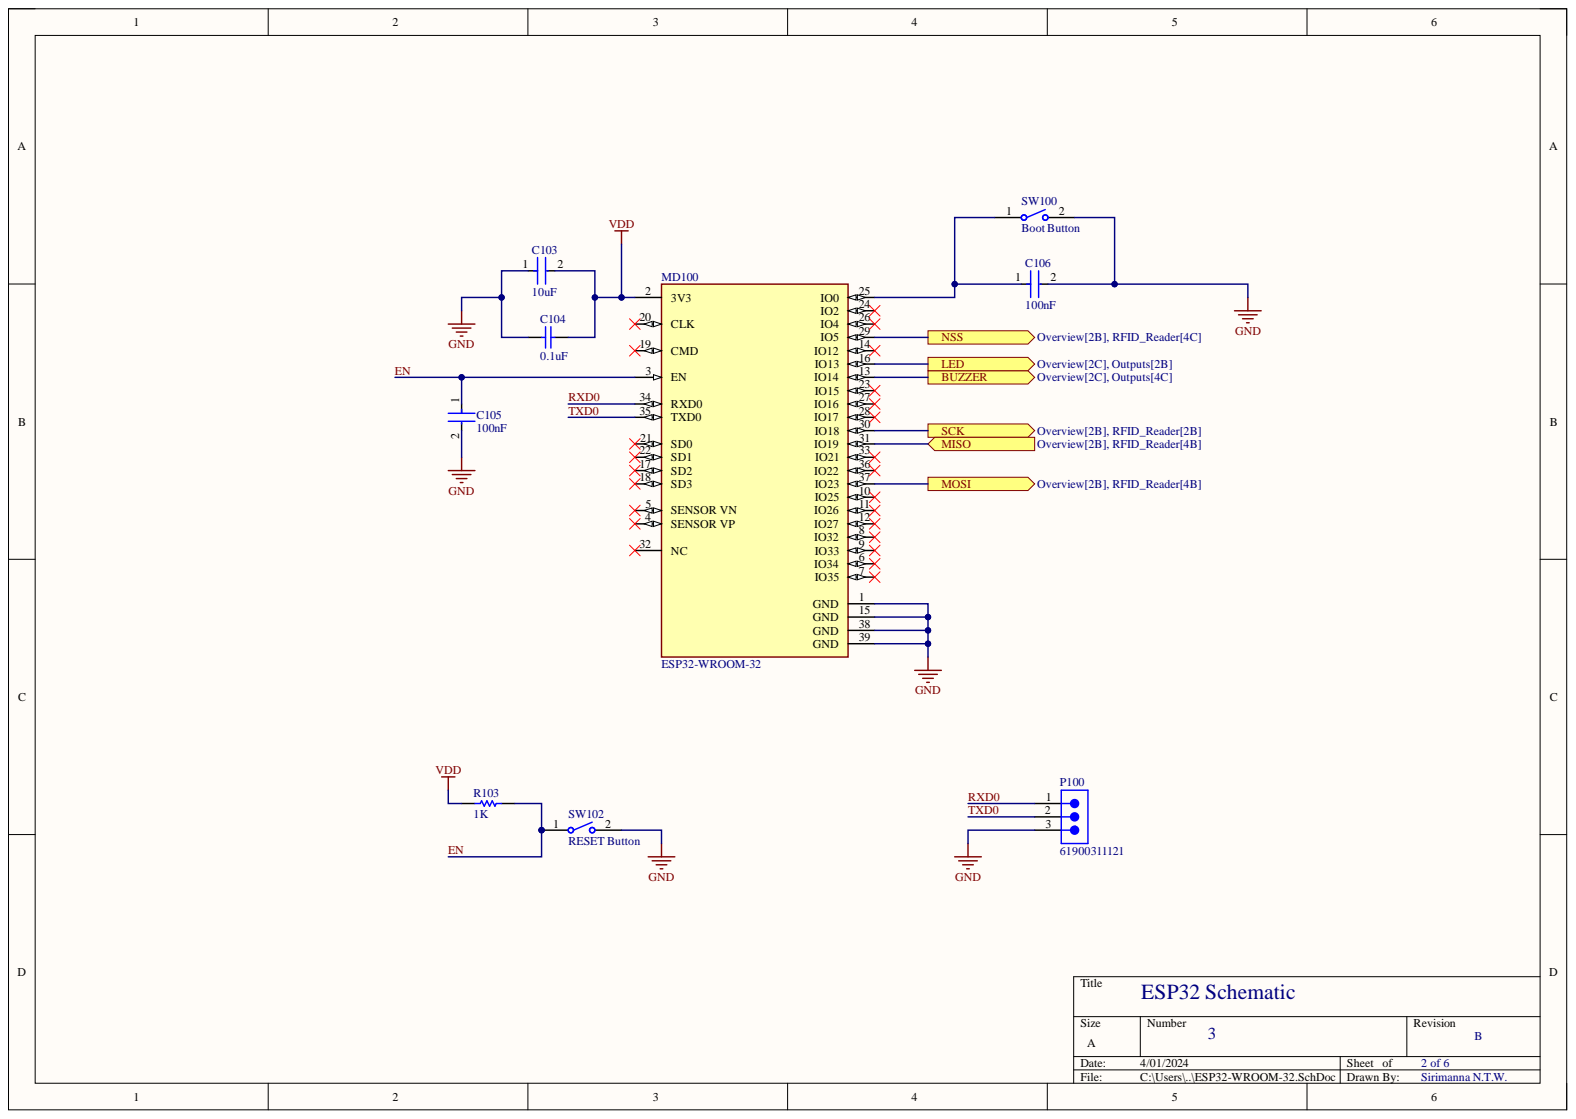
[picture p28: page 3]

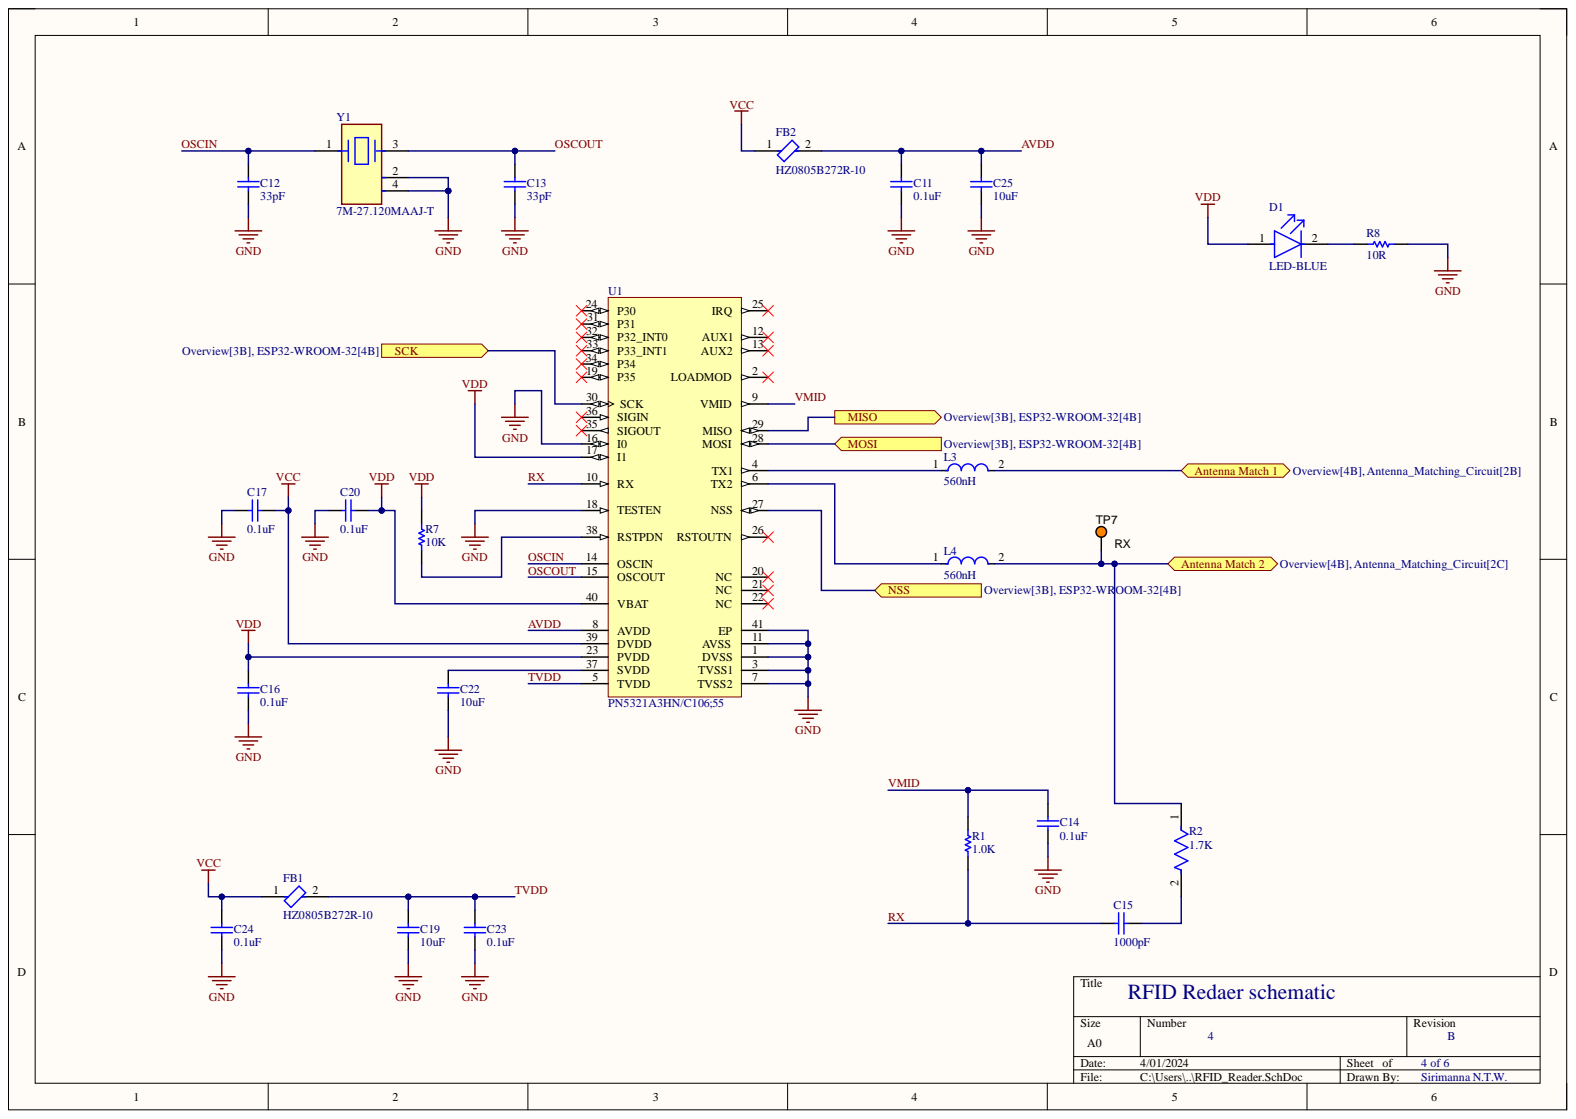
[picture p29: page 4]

R7 | RSTPDN 38
10K OSCIN | OSCIN 14

SVDD 37

TVDD | TVDD 5

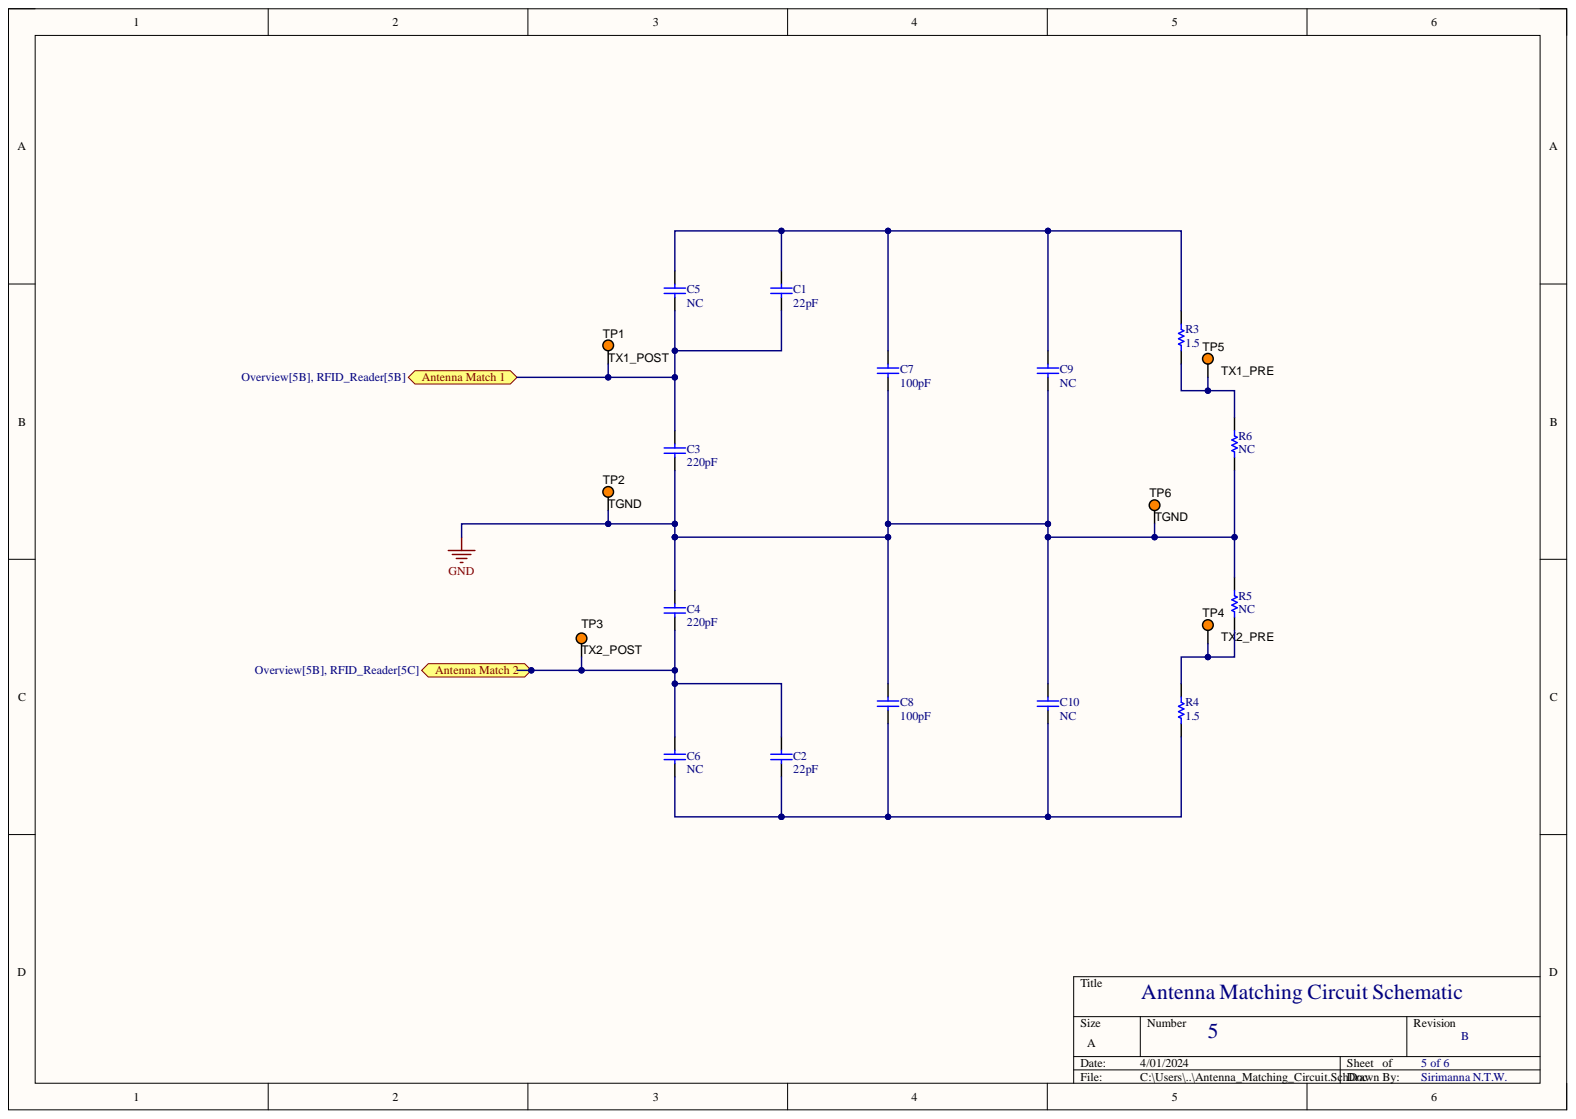
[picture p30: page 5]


Buzzer and LED Schematic


Line # | Name | Description | Designator | Revision ID | Revision State | Revision Status | Quantity | Manufacturer 1 | Manufacturer Part Number 1 | Manufacturer Lifecycle 1 | Supplier 1 | Supplier Part Number 1 | Supplier Unit Price 1 | Supplier Subtotal 1
| 22pF, 220pF, NC, 100pF, 0.1uF, 33pF, 1000pF, 10uF | Chip Capacitor, 0.1 uF, +/- 10%, 50 V, -55 to 125 degC, 0805 (2012 Metric), RoHS, Tape and Reel | C1, C2, C3, C4, C5, C6, C7, C8, C9, C10, C11, C12, C13, C14, C15, C16, C17, C19, C20, C22, C23, C24, C25 | | Unknown server | | 23
| 470uF | CAP ALUM POLY HYB 100UF 50V SMD | C100 | | Unknown server | | 1 | Panasonic | EEH-ZA1H101P | Volume Production | Newark | 62W7360 | 2.45 | 2.45
| 330uF | CAP ALUM 330UF 20% 35V SMD | C101 | | Unknown server | | 1 | Panasonic | EEE-FK1V331AP | Volume Production | Newark | 85AK4248 | 0.951 | 0.951
| 10uF | CAP CER 10UF 10V X5R 0805 | C103 | | Unknown server | | 1
| 0.1uF | | C104 | | Unknown server | | 1
| 100nF | General Purpose Ceramic Capacitor, 0805, 100nF, 10%, X7R, 15%, 100V | C105 | | Unknown server | | 1
| 100nF | CAP CER 0.1UF 50V X7R 0805 | C106 | | Unknown server | | 1
| LED-BLUE | LED BLUE CLEAR 0805 SMD | D1 | | Unknown server | | 1
| CMS06(TE12L,Q,M) | DIODE SCHOTTKY 30V 2A MFLAT | D100 | | Unknown server | | 1 | Toshiba | CMS06(TE12L,Q,M) | Volume Production | Arrow Electronics | CMS06(TE12L,Q,M) | 0.4278 | 0.4278
| RS1M | DIODE GEN PURP 1KV 1A SMA | D103 | | Unknown server | | 1
| SML-LX1206IC-TR | LED Red, 65 mW, -40 to 85 degC, 2-Pin SMD, RoHS, Tape and Reel | DS100 | | Unknown server | | 1 | Lumex | SMLLX1206ICTR | Volume Production | Arrow Electronics | SML-LX1206IC-TR | 0.2518 | 0.2518
| HSMG-C170 | Chip LED, Green, 2.2 V, -40 to 85 degC, 2-Pin SMD, Pb-Free, Tape and Reel | DS101 | | Unknown server | | 1
| HZ0805B272R-10 | FERRITE BEAD 100 OHM 0805 1LN | FB1, FB2 | | Unknown server | | 2
| B2B-XH-A(LF)(SN), Switch | CONN HEADER VERT 2POS 2.5MM, To power Switch | J100, J101 | | Unknown server | | 2 JST | | B2B-XH-A(LF)(SN) | Volume Production | Newark | 73M9415 | 0.077 | 0.154
| 560nH | Multilayer Type Inductor for General Circuits, 0805 (2012), 0.56μH, 10%, 0.63Ω, 150mA | L3, L4 | | Unknown server | | 2
| SRR1210-101M | FIXED IND 100UH 2.5A 135MOHM SMD | L100 | | Unknown server | | 1 | Bourns | SRR1210-101M | Volume Production | Mouser | 652-SRR1210-101M | 1.23 | 1.23
| BUZZER | AUDIO PIEZO TRANSDUCER 30V TH | LS100 | | Unknown server | | 1
| ESP32-WROOM-32 | RX TXRX MOD WIFI SURFACE MOUNT | MD100 | | Unknown server | | 1 | Espressif Systems | ESP32-WROOM-32
| 61900311121 | | P100 | | Unknown server | | 1
| BC847C | NPN Silicon AF Transistor, 45 V VCEO, 100 mA IC, SOT23, Reel, Green | Q100 | | Unknown server | | 1
| 1.0K | | R1 | | Unknown server | | 1
| 1.7K | RES Thick Film, 1.5kΩ, 1%, 0.125W, 100ppm/°C, 0805 | R2 | | Unknown server | | 1
| 1.5 | | R3, R4 | | Unknown server | | 2
| NC | | R5, R6 | | Unknown server | | 2
| 10K | Chip Resistor, 10 KOhm, +/- 1%, 0.125 W, -55 to 155 degC, 0805 (2012 Metric), RoHS, Tape and Reel | R7 | | Unknown server | | 1
| 10R | Chip Resistor, 10 Ohm, +/- 1%, 0.125 W, -55 to 155 degC, 0805 (2012 Metric), RoHS, Tape and Reel | R8, R102 | | Unknown server | | 2
| 2K | Resistor | R100 | | Not managed | | 1
| 1K | Chip Resistor, 1 KOhm, +/- 1%, 125 mW, -55 to 155 degC, 0805 (2012 Metric), RoHS, Tape and Reel | R103 | | Unknown server | | 1
| 220R | | R104 | | Unknown server | | 1
| Boot Button, RESET Button | FSMSM Push Button Switch, 50 mA, -35 to 85 degC, 2-Pin SMD, RoHS, Bulk | SW100, SW102 | | Unknown server | | 2
| TX1_POST, TGND, TX2_POST, TX2_PRE, TX1_PRE, RX | Test Point, Orange, 1-Pin THD, RoHS | TP1, TP2, TP3, TP4, TP5, TP6, TP7 | | Unknown server | | 7
| 12V, 3.3V, 12V_IN, GND | Test Point, Red, Through Hole, RoHS, Bulk | TP100, TP101, TP102, TP103 | | Unknown server | | 4
| PN5321A3HN/C106;55 | NFC Controller, 13.56 MHz, -30 to 85 degC, 40-Pin HVQFN (SOT618-1), RoHS, Tray | U1 | | Unknown server | | 1
| LM2596S-3.3 | SIMPLE SWITCHER® Power Converter 150 KHz 3A Step-Down Voltage Regulator, 5-pin TO-263 | U100 | | Unknown server | | 1 | TI National Semiconductor | LM2596S-3.3 | End of Life | Digikey | LM2596S-3.3-ND | 9.16 | 9.16
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

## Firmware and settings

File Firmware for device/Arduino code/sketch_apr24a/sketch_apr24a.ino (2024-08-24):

#include <SPI.h>
#include <Adafruit_PN532.h>
#include <WiFi.h>
#include <PubSubClient.h>

#define PN532_SCK  (5) // SCK (Serial Clock)
#define PN532_MISO (19) // MISO (Master In Slave Out)
#define PN532_MOSI (23) // MOSI (Master Out Slave In)
#define PN532_SS   (18) // SS (Slave Select)

#define Buzzer 14
#define Indicator 13

int size1 = 50;
int size2 = 200;

char details[40];
char detailsLong[250];

WiFiClient espClient;
PubSubClient mqttClient(espClient);

Adafruit_PN532 nfc(PN532_SCK, PN532_MISO, PN532_MOSI, PN532_SS);
String idcard;
String idcardOld;

void setup() {
  Serial.begin(115200);     

  setupWifi();

  setupMqtt();

  setupPn532();

  pinMode(Buzzer, OUTPUT);
  digitalWrite(Buzzer, LOW);

  pinMode(Indicator, OUTPUT);
  digitalWrite(Indicator, LOW);
}

void loop() {

  if (!mqttClient.connected()){
    connectToBroker();
  }

  mqttClient.loop();

  readPn532();
}

void setupWifi() {

  WiFi.begin("NTWS-4G", "XXXXXXXXXXXX");

  while (WiFi.status() != WL_CONNECTED) {
    delay(500);
  }
}

void setupMqtt() {
  mqttClient.setServer("test.mosquitto.org", 1883);      
}

void setupPn532(){
  nfc.begin();
  uint32_t versiondata = nfc.getFirmwareVersion();
  if (! versiondata) {     
    while (1); // halt
  }

  nfc.setPassiveActivationRetries(0xFF);
}

void readPn532(){
  uint8_t success;
  uint8_t uid[] = { 0, 0, 0, 0, 0, 0, 0 };  // Buffer to store the returned UID
  uint8_t uidLength;
  success = nfc.readPassiveTargetID(PN532_MIFARE_ISO14443A, uid, &uidLength);
  if (success) {
    // Display some basic information about the card

    idcardOld = idcard;

    idcard = "";
    for (byte i = 0; i <= uidLength - 1; i++) {
      idcard += (uid[i] < 0x10 ? "0" : "") + String(uid[i], HEX);
    }

    if (idcard != idcardOld){
      String(idcard).toCharArray(details, size1);
      mqttClient.publish("210610H-CardDetails", details);
      Indicate();
    }
  }
}

void connectToBroker(){
  while (!mqttClient.connected()){

    if (mqttClient.connect("210610H-forklift")){
      String("RFID based asset tracking device CONNECTED").toCharArray(details, size2);
      mqttClient.publish("210610H-Details", details);
    }
    else{
      delay(5000);
    }
  }
}

void Indicate(){
  tone(Buzzer, 400);
  digitalWrite(Indicator, HIGH);
  delay(400);

  noTone(Buzzer);
  digitalWrite(Indicator, LOW);
}

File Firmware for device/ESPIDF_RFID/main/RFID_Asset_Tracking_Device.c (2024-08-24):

#include <string.h>
#include <stdio.h>
#include <stdint.h>
#include <stddef.h>
#include <stdlib.h>
#include "freertos/FreeRTOS.h"
#include "freertos/task.h"
#include "freertos/queue.h"
#include "freertos/timers.h"
#include "freertos/semphr.h"
#include "freertos/event_groups.h"
#include "esp_system.h"
#include "esp_event.h"
#include "esp_log.h"
#include "nvs_flash.h"
#include "esp_wifi.h"
#include "mqtt_client.h"
#include "driver/gpio.h"
#include "esp_timer.h"
#include "esp_netif.h"
#include "esp_http_server.h"
#include "driver/spi_master.h"
#include "lwip/sockets.h"
#include "lwip/dns.h"
#include "lwip/netdb.h"
#include "pn532.h"

#define WIFI_SSID "xxxxxxx"
#define WIFI_PASS "xxxxxxx"

#define LED_PIN GPIO_NUM_13
#define BUZZER_PIN GPIO_NUM_14

#define TAG "RFID_TRACKER"

// Global variables
pn532_t nfc;
char details[50];
char detailsLong[250];
char idcard[20];
char idcardOld[20];

void Indicate()
{
    gpio_set_level(LED_PIN, 1);
    gpio_set_level(BUZZER_PIN, 1);
    vTaskDelay(400 / portTICK_PERIOD_MS);
    gpio_set_level(LED_PIN, 0);
    gpio_set_level(BUZZER_PIN, 0);
}

void readPn532()
{
    uint8_t uid[7];
    uint8_t uidLength;

    // Corrected function call with proper parameters
    if (pn532_readPassiveTargetID(&nfc, 0, uid, &uidLength, 1000))
    { // Added cardbaudrate and timeout parameters
        snprintf(idcardOld, sizeof(idcardOld), "%s", idcard);
        memset(idcard, 0, sizeof(idcard));

        for (int i = 0; i < uidLength; i++)
        {
            snprintf(idcard + strlen(idcard), sizeof(idcard) - strlen(idcard), "%02X", uid[i]);
        }

        if (strcmp(idcard, idcardOld) != 0)
        {
            snprintf(details, sizeof(details), "%s", idcard);
            // esp_mqtt_client_publish(mqttClient, "CardDetails", details, 0, 1, 0);
            Indicate();
        }
    }
}

void setupPn532()
{
    pn532_begin(&nfc); // Assuming pn532_initialize should be pn532_begin
    uint32_t versiondata = pn532_getFirmwareVersion(&nfc);

    if (versiondata == 0)
    {
        // ESP_LOGE(TAG, "Error: PN532 not detected. Restarting in 1 second...");
        printf("Error: PN532 not detected. Restarting in 1 second...\n");

        vTaskDelay(1000 / portTICK_PERIOD_MS);
        esp_restart();
    }

    ESP_LOGI(TAG, "Found chip PN5%02lX", (unsigned long)((versiondata >> 24) & 0xFF));
    ESP_LOGI(TAG, "Firmware ver. %lu.%lu", (unsigned long)((versiondata >> 16) & 0xFF), (unsigned long)((versiondata >> 8) & 0xFF));

    pn532_setPassiveActivationRetries(&nfc, 0xFF);
    Indicate();
}

////////////

static void wifi_event_handler(void *event_handler_arg, esp_event_base_t event_base, int32_t event_id, void *event_data)
{
    switch (event_id)
    {
    case WIFI_EVENT_STA_START:
        printf("WiFi connecting WIFI_EVENT_STA_START ... \n");
        break;
    case WIFI_EVENT_STA_CONNECTED:
        printf("WiFi connected WIFI_EVENT_STA_CONNECTED ... \n");
        break;
    case WIFI_EVENT_STA_DISCONNECTED:
        printf("WiFi lost connection WIFI_EVENT_STA_DISCONNECTED ... \n");
        break;
    case IP_EVENT_STA_GOT_IP:
        printf("WiFi got IP ... \n\n");
        break;
    default:
        break;
    }
}

void wifi_connection()
{
    nvs_flash_init();
    esp_netif_init();
    esp_event_loop_create_default();
    esp_netif_create_default_wifi_sta();
    wifi_init_config_t wifi_initiation = WIFI_INIT_CONFIG_DEFAULT();
    esp_wifi_init(&wifi_initiation);
    esp_event_handler_register(WIFI_EVENT, ESP_EVENT_ANY_ID, wifi_event_handler, NULL);
    esp_event_handler_register(IP_EVENT, IP_EVENT_STA_GOT_IP, wifi_event_handler, NULL);
    wifi_config_t wifi_configuration = {
        .sta = {
            .ssid = WIFI_SSID,
            .password = WIFI_PASS}};
    esp_wifi_set_config(ESP_IF_WIFI_STA, &wifi_configuration);
    esp_wifi_set_mode(WIFI_MODE_STA);
    esp_wifi_start();
    esp_wifi_connect();
}

///////////////

static void log_error_if_nonzero(const char *message, int error_code)
{
    if (error_code != 0) {
        ESP_LOGE(TAG, "Last error %s: 0x%x", message, error_code);
    }
}

static void mqtt_event_handler(void *handler_args, esp_event_base_t base, int32_t event_id, void *event_data)
{
    ESP_LOGD(TAG, "Event dispatched from event loop base=%s, event_id=%" PRIi32 "", base, event_id);
    esp_mqtt_event_handle_t event = event_data;
    esp_mqtt_client_handle_t client = event->client;
    int msg_id;
    switch ((esp_mqtt_event_id_t)event_id) {
    case MQTT_EVENT_CONNECTED:
        ESP_LOGI(TAG, "MQTT_EVENT_CONNECTED");
        msg_id = esp_mqtt_client_publish(client, "/topic/qos1", "data_3", 0, 1, 0);
        ESP_LOGI(TAG, "sent publish successful, msg_id=%d", msg_id);

        msg_id = esp_mqtt_client_subscribe(client, "/topic/qos0", 0);
        ESP_LOGI(TAG, "sent subscribe successful, msg_id=%d", msg_id);

        msg_id = esp_mqtt_client_subscribe(client, "/topic/qos1", 1);
        ESP_LOGI(TAG, "sent subscribe successful, msg_id=%d", msg_id);

        msg_id = esp_mqtt_client_unsubscribe(client, "/topic/qos1");
        ESP_LOGI(TAG, "sent unsubscribe successful, msg_id=%d", msg_id);
        break;
    case MQTT_EVENT_DISCONNECTED:
        ESP_LOGI(TAG, "SERVER_DISCONNECTED");
        break;

    case MQTT_EVENT_SUBSCRIBED:
        ESP_LOGI(TAG, "MQTT_EVENT_SUBSCRIBED, msg_id=%d", event->msg_id);
        msg_id = esp_mqtt_client_publish(client, "/topic/qos0", "data", 0, 0, 0);
        ESP_LOGI(TAG, "sent publish successful, msg_id=%d", msg_id);
        break;
    case MQTT_EVENT_UNSUBSCRIBED:
        ESP_LOGI(TAG, "MQTT_EVENT_UNSUBSCRIBED, msg_id=%d", event->msg_id);
        break;
    case MQTT_EVENT_PUBLISHED:
        ESP_LOGI(TAG, "MQTT_EVENT_PUBLISHED, msg_id=%d", event->msg_id);
        break;
    case MQTT_EVENT_DATA:
        ESP_LOGI(TAG, "MQTT_EVENT_DATA");
        printf("TOPIC=%.*s\r\n", event->topic_len, event->topic);
        printf("DATA=%.*s\r\n", event->data_len, event->data);
        break;
    case MQTT_EVENT_ERROR:
        ESP_LOGI(TAG, "MQTT_EVENT_ERROR");
        if (event->error_handle->error_type == MQTT_ERROR_TYPE_TCP_TRANSPORT) {
            log_error_if_nonzero("reported from esp-tls", event->error_handle->esp_tls_last_esp_err);
            log_error_if_nonzero("reported from tls stack", event->error_handle->esp_tls_stack_err);
            log_error_if_nonzero("captured as transport's socket errno",  event->error_handle->esp_transport_sock_errno);
            ESP_LOGI(TAG, "Last errno string (%s)", strerror(event->error_handle->esp_transport_sock_errno));

        }
        break;
    default:
        ESP_LOGI(TAG, "Other event id:%d", event->event_id);
        break;
    }
}
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
